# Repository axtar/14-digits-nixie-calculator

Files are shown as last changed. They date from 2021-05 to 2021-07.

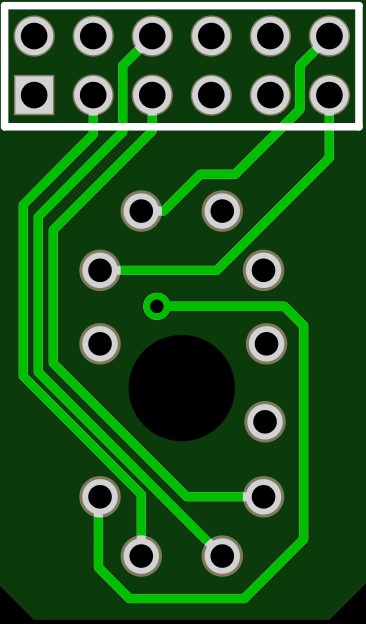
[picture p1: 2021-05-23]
PCB/Pictures/Boards 2D/Nixie Calculator IN-17 Socket Bottom 2D.jpg

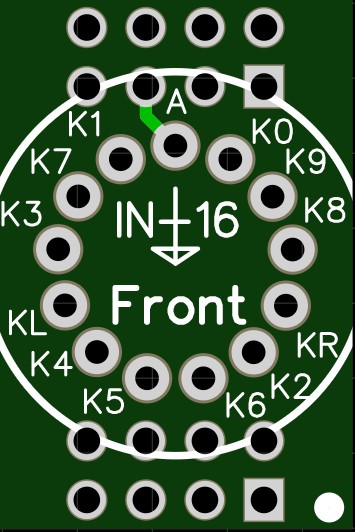
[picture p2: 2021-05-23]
PCB/Pictures/Boards 2D/Nixie Calculator IN-16 Socket Top 2D.jpg

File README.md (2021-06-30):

# 14-digits nixie calculator
## This repository contains some information and ideas for building a nixie calculator.
## WARNING: nixies need high voltage to light up. If you choose to build the calculator, you are doing so at your own risk.
### Hardware status: ready to be reviewed, software status: under construction...
#### Notes:
- I am not affiliated with any of the service providers named in this project.<br>
- **This is not a complete project. Neither the schematic nor the PCB design for the high voltage power supply will be made available.**<br>

readme

**Features:**
-	two versions: IN-16 and IN-17
-	14 digits with decimal points and minus sign
-	socket boards for easy tube replacement
-	mechanical keyboard with 35 switches
-	custom keycap legends and colors
-	15 math operations - the functionality can be extended by adding a second level of functions
-	5 memory operations
-	RTC with battery
-	clock mode
-	stopwatch mode 
-	ESP32 based controller board
-	connectors for PIR, GPS and temperature sensor
-	12V DC input voltage
-	open-source firmware
-	all the settings are adjusted using the keyboard, no network connection is needed
-	3D printed case

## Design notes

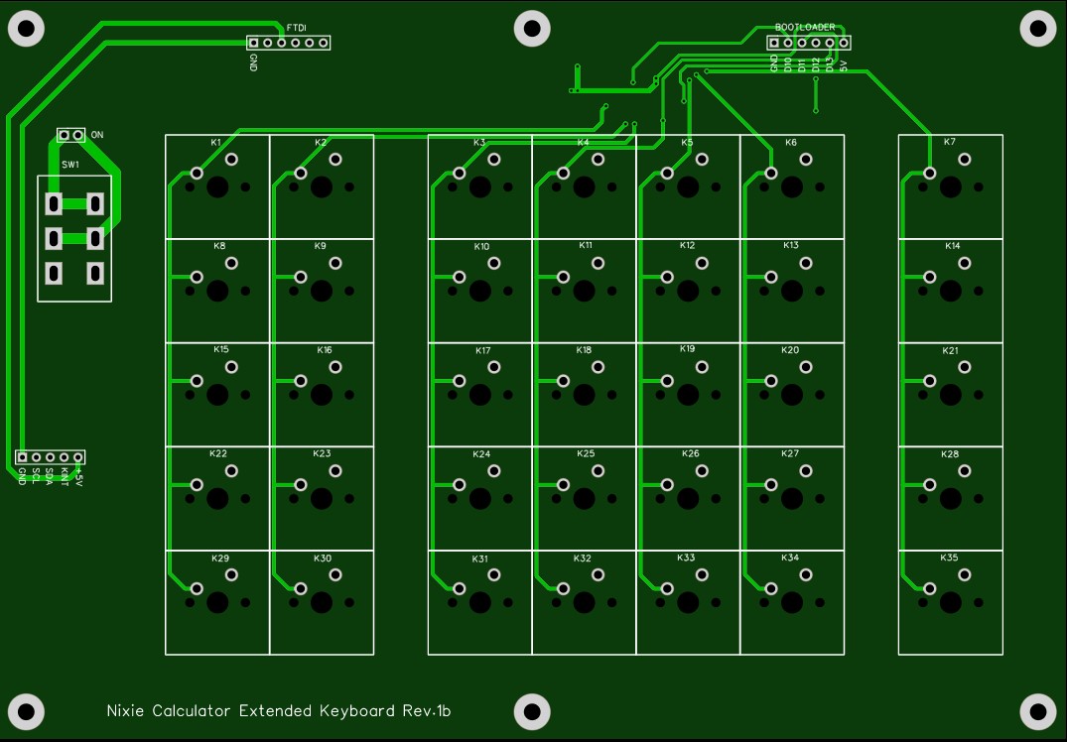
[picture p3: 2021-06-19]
PCB/Pictures/Boards 2D/Nixie Calculator Extended Keyboard Top 2D.jpg

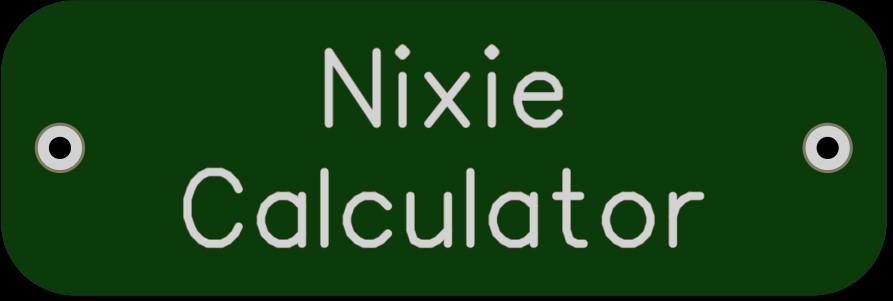
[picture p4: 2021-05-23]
PCB/Pictures/Boards 2D/Nixie Calculator Label Top 2D.jpg

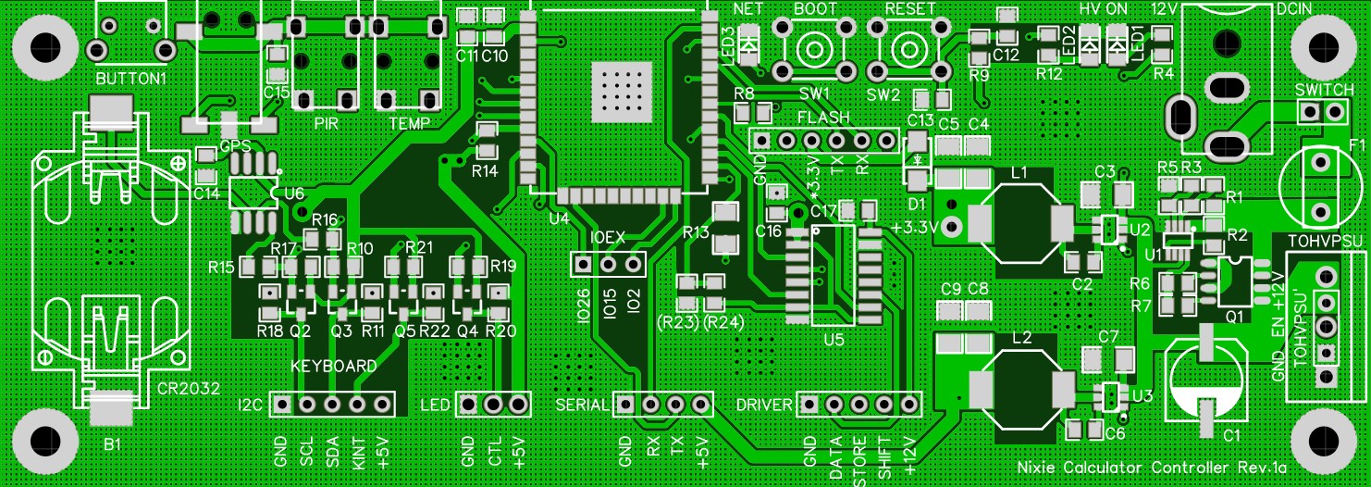
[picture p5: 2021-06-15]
PCB/Pictures/Boards 2D/Nixie Calculator Controller Top 2D.jpg

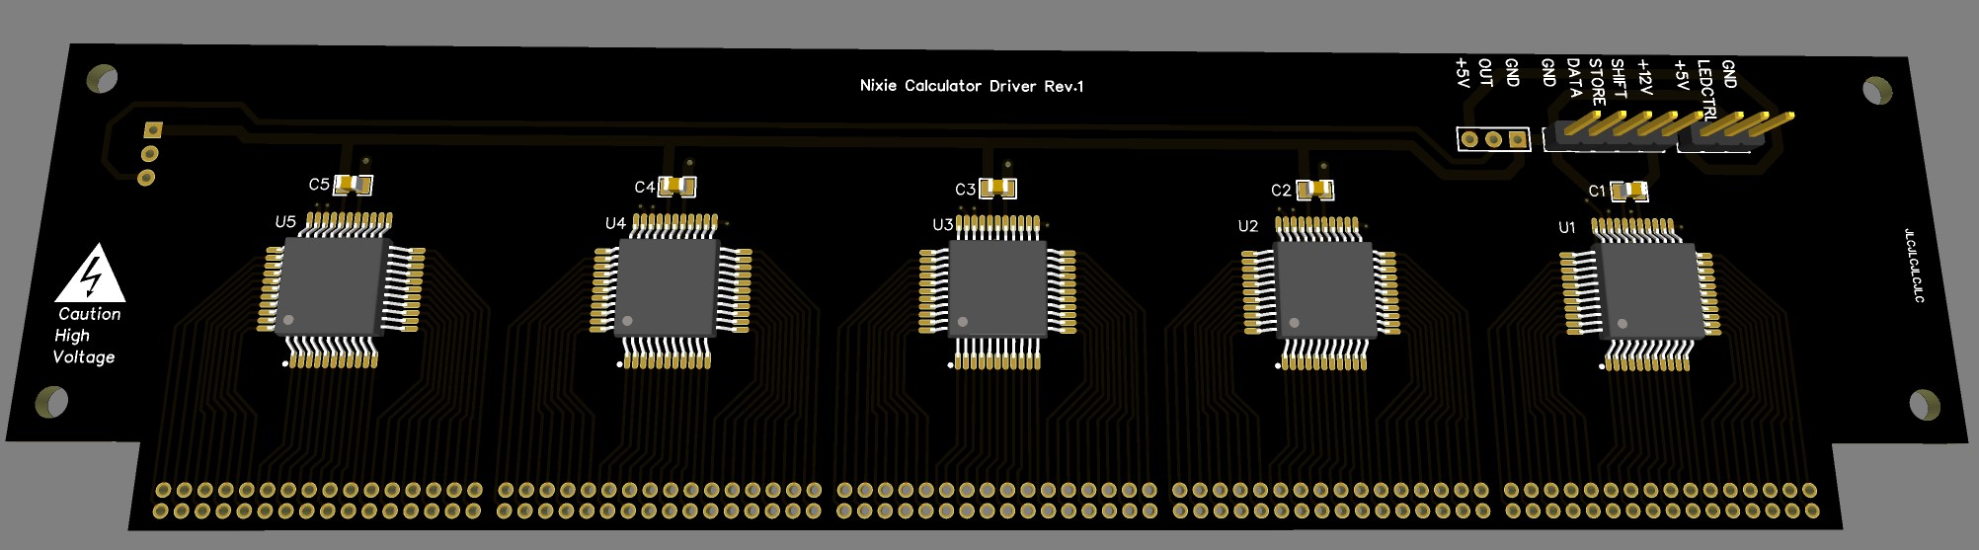
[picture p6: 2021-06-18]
PCB/Pictures/Boards 3D/Nixie Calculator IN-16 Driver Bottom 3D.jpg

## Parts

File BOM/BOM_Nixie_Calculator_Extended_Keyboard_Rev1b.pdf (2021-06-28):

BOM Nixie Calculator Extended Keyboard Rev.1b | 28/06/2021
ID | Quantity | Value | Additional | Designator | Footprint | Type | Manufacturer Part | Manufacturer | Supplier Part | Supplier
1 | 1 | 1M | 1/4W | R1 | 0805 | Resistor | RK73H2ATTD1004F | KOA Speer
2 | 1 | 10k | 1/4W | R2 | 0805 | Resistor | RK73H2ATTD1002F | KOA Speer
3 | 1 | 1k | 1/4W | R3 | 0805 | Resistor | RK73H2ATTD1001F | KOA Speer
4 | 2 | 150 | 1/4W | R4,R5 | 0805 | Resistor | RK73H2ATTD1500F | KOA Speer
5 | 2 | 100n | 50V | C1,C2 | 0805 | Capacitor | C0805C104M5RACTU | KEMET
6 | 2 | 22p | 50V | C3,C4 | 0805 | Capacitor | C0805C220K5HACTU | KEMET
7 | 36 | 1N4148W | | D1-D36 | SOD-123 | Diode | 1N4148W-7-F | Diodes Incorporated
8 | 1 | Crystal 16MHz | | X1 | HC-49/US SMD | Crystal
9 | 1 | ATMEGA328P-AU | | U1 | TQFP-32 | MCU | ATMEGA328P-AU | AVR
10 | 35 | Cherry MX blue | | K1-K35 | | Pushbutton switch | MX1A-E1NW | CHERRY
11 | 1 | Slide switch | | SW1 | | Slide switch | S202031MS02Q | C&K
12 | 1 | 1x2 header/2.54mm | male, right angle | ON | | Header
13 | 1 | 1x5/header/2.54mm | male, right angle | H1 (GND,SCL,SDA,KINT,+5V) | | Header
14 | 2 | 1x6/header/2.54mm | male | FTDI, BOOTLOADER | | Header

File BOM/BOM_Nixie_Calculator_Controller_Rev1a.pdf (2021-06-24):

BOM Nixie Calculator Controller Rev.1a | 24/06/2021
ID | Quantity | Value | Additional | Designator | Footprint | Type | Manufacturer Part | Manufacturer | Supplier Part | Supplier
1 | 1 | 1.2M | 1/4W, 1% | R1 | 0805 | Resistor | RK73H2ATTD1204F | KOA Speer
2 | 1 | 510k | 1/4W | R2 | 0805 | Resistor | RK73H2ATTD5103F | KOA Speer
3 | 1 | 15k | 1/4W, 1% | R3 | 0805 | Resistor | RK73H2ATTD1502F | KOA Speer
4 | 1 | 1k | 1/4W | R4 | 0805 | Resistor | RK73H2ATTDD1001F | KOA Speer
5 | 1 | 47k | 1/4W, 1% | R5 | 0805 | Resistor | RK73H2ATTD4702F | KOA Speer
6 | 2 | 10 | 1/4W | R6,R7 | 0805 | Resistor | RK73H2ATTD10R0F | KOA Speer
7 | 2 | 330 | 1/4W | R8,R12 | 0805 | Resistor | RK73H2ATTD3300F | KOA Speer
8 | 2 | 3.9k | 1/4W | R10,17 | 0805 | Resistor | RK73H2ATTD3901F | KOA Speer
9 | 3 | 4.7k | 1/4W | R11,R14,R18 | 0805 | Resistor | RK73H2ATTD4701F | KOA Speer
10 | 5 | 10k | 1/4W | R9,R19-R22 | 0805 | Resistor | RK73H2ATTD1002F | KOA Speer
11 | 3 | 150 | 1/4W | R13,R15,R16 | 0805 | Resistor | RK73H2ATTD1500F | KOA Speer
12 | 1 | see schematic | 1/4W | R23 | 0805 | Resistor
13 | 1 | see schematic | 1/4W | R24 | 0805 | Resistor
14 | 1 | 220u | 25V | C1 | 8mm dia | Capacitor | GYB1E221MCQ1GS | Nichicon
15 | 9 | 100n | 50V | C2,C6,C10,C12-C17 | 0805 | Capacitor | C0805C104M5RACTU | KEMET
16 | 2 | 10u | 25V | C3,C7 | 1206 | Capacitor | TMK316BJ106MLHT | Taiyo Yuden
17 | 4 | 22u | 25V | C4,C5,C8,C9 | 1206 | Capacitor | TMK316BBJ226ML-T | Taiyo Yuden
18 | 1 | 10u | 16V | C11 | 0805 | Capacitor | GRM21BR61C106KE15K | Murata Electronics
19 | 1 | B340A-13-F | | D1 | SMA | Diode | B340A-13-F | Diodes Incorporated
20 | 1 | LED yellow | | LED1 | 1206 | LED | 599-0240-007F | Dialight
21 | 1 | LED red | | LED2 | 1206 | LED | 599-0210-007F | Dialight
22 | 1 | LED blue | | LED3 | 1206 | LED | 599-0291-007F | Dialight
23 | 1 | 3.9uH inductor | | L1 | 8043 | Inductor | SRU8043-3R9Y | Bourns
24 | 1 | 4.7uH inductor | | L2 | 8043 | Inductor | SRU8043-4R7Y | Bourns
25 | 1 | LTC4365 | | U1 | SOT-8 | IC | LTC4365ITS8-1#TRMPBF | Analog Devices
26 | 1 | AP63203WU-7 | | U2 | TSOT-26-6 | IC | AP63203WU-7 | Diodes Incorporated
27 | 1 | AP63205WU-7 | | U3 | TSOT-26-6 | IC | AP63205WU-7 | Diodes Incorporated
28 | 1 | ESP-WROOM-32E | 16MB | U4 | | MC module | ESP32-WROOM-32E | Espressif Systems
29 | 1 | CD40109B | | U5 | SO-16 | IC | CD40109BNSR | Texas Insruments
30 | 1 | DS3231MZ+ | | U6 | SOIC-8 | IC | DS3231MZ+TRL | Maxim Integrated
31 | 1 | CSD88537ND Dual N | | Q1 | SOIC-8 | Mosfet | CSD88537ND | Texas Insruments
32 | 4 | BSS138 | | Q2,Q3,Q4,Q5 | SOT-23 | Mosfet | BSS138N H6327 | Infineon Technologies
33 | 1 | DC power connector | | DCIN | | DC power connector | PJ-057AH | CUI Devices
34 | 1 | Fuse 1.25A Fast | | F1 | | Fuse | 0034.6015 | Schurter
35 | 1 | Fuse holder | | | | Fuse holder | 0031.7601 | Schurter
36 | 2 | Tactile Switch | | SW1,SW2 | | Switch | TL1105AF160Q | E-Switch
37 | 1 | Tactile Switch | right angle | BUTTON1 | | Switch | TL1105SF160Q | E-Switch
38 | 1 | CR2032 battery holder | | | | Battery holder | SMTU2032-LF | Renata
39 | 1 | CR2032 battery | | B1 | | Battery
40 | 1 | 1x2 header/2.54mm | male | SWITCH | | Header
41 | 2 | 1x3 header/2.54mm | male | LED,IOEX | | Header
42 | *1 | 1x4 header/2.54mm | male | SERIAL | | Header
43 | 2 | 1x5 header/2.54mm | male | DRIVER,I2C | | Header
44 | 1 | 1x6 header/2.54mm | male | FLASH | | Header
45 | 1 | 3 poles terminal block | | TOHVPSU | | Fixed Terminal Block | TB006-508-03BE | CUI Devices
46 | 2 | 3.5mm connector | | TEMP,PIR | see datasheet | 3.5mm connector, 3 pin | 1503 07 | Lumberg
47 | 1 | 3.5mm connector | | GPS | see datasheet | 3.5mm connector, 4 pin | 1503 13 VP3 | Lumberg
* do not populate

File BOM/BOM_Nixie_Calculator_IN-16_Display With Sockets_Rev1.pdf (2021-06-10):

BOM Nixie Calculator IN-16 Display With Sockets Rev.1 | 09/06/2021
ID | Quantity | Value | Additional | Designator | Footprint | Type | Manufacturer Part | Manufacturer | Supplier Part | Supplier
1 | 14 | 15k | 1/4W | R1,R3,R5,R7,R9,R11,R13,R15;R17,R19,R21,R23,R 25,R27 | 0805 | Resistor | RK73H2ATTD1502F | KOA Speer
2 | 14 | 100k | 1/4W | R2,R4,R6,R8,R10,R12,R14,R16,R18,R20,R22,R24, R26,R28 | 0805 | Resistor | RK73H2ATTDD1003F | KOA Speer
3 | 1 | 270k | 1/4W | R29 | 0805 | Resistor | RK73H2ATTD2703F | KOA Speer
4 | 28 | 2x4 header socket 2.00mm | female, 250V | H1_X-H14_X | | Header | A2005HWV-2x4P | CJT
5 | 14 | IN-16 socket board | | | | Board
6 | 14 | IN-16 Nixie | | | | Nixie tube
7 | 28 | 2x4 header 2.00mm | male, 250V | | | Header | A2005WV-2x4P | CJT
8 | 1 | Neon 4mm | | E1 | | Neon lamp
9 | *10 | 2x8 header 2.00mm | male, right angle, 250V | H1-H5 x 2 | | Header | A2005WR-2x8P | CJT
* | 2x16 difficult to find

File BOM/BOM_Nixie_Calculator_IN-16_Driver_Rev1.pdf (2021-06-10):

BOM Nixie Calculator Driver Rev.1 | 09/06/2021
ID | Quantity | Value | Additional | Designator | Footprint | Type | Manufacturer Part | Manufacturer | Supplier Part | Supplier
1 | 6 | 100n | 50V | C1-C6 | 0805 | Capacitor | C0805C104M5RACTU | KEMET
2 | 5 | HV5622 | | U1-U5 | PQFP-44 | IC | HV5622PG-G | Microchip Technology
3 | 6 | Neopixel RGB SK6812 | | D1-D6 | 5050 | RGB LED | SK6812
4 | 1 | 1x3 header, 2.54mm | male | H7 (LED) | | Header
5 | 1 | 1x5 header, 2.54mm | male | H6 (DRIVER) | | Header
H8,H9 (MOTION DETECTOR): do not populate

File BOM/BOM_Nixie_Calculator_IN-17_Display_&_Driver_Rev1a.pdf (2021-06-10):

BOM Nixie Calculator IN-17 Display & Driver With Sockets Rev.1a | 09/06/2021
ID | Quantity | Value | Additional | Designator | Footprint | Type | Manufacturer Part | Manufacturer | Supplier Part | Supplier
1 | 15 | 270k | 1/4W | R2,R4,R6,R8,R10,R12,R14,R16,R 18,R20,R22,R24,R26,R28.R29 | 0805 | Resistor | RK73H2ATTD2703F | KOA Speer
2 | 14 | 22k | 1/4W | R1,R3,R5,R7;R9,R11,R13,R15,R1 7,R19,R21,R23,R25,R27 | 0805 | Resistor | RK73H2ATTD2202F | KOA Speer
3 | 6 | 100n | 50V | C1-C6 | 0805 | Capacitor | C0805C104M5RACTU | KEMET
4 | 5 | HV5622 | | U1-U5 | PQFP-44 | IC | HV5622PG-G | Microchip Technology
| 6 | Neopixel RGB SK6812 | | D1-D6 | 5050 | RGB LED | SK6812
6 | 14 | IN-17 socket board | | | | Board
7 | 14 | IN-17 Nixie | | | | Nixie tube
8 | 14 | 2x6 header 2.00mm | male, 250V | | | Header | A2005WV-2x6P | CJT
9 | 14 | Neon 3mm | | E1-E14
10 | 1 | Neon 4mm | | E15
11 | 14 | 2x6 header 2.00mm | female, 250V | | | | A2005HWV-2x6P | CJT
12 | 1 | 1x5 header 2.54mm | male, right angle | H0 (DRIVER) | | Header
13 | 1 | 1x3 header 2.54mm | male, right angle | H15 (LED) | | Header
14 | 1 | 2 poles terminal block | | HVPSU | | Fixed terminal block | TB006-508-02BE | CUI Devices

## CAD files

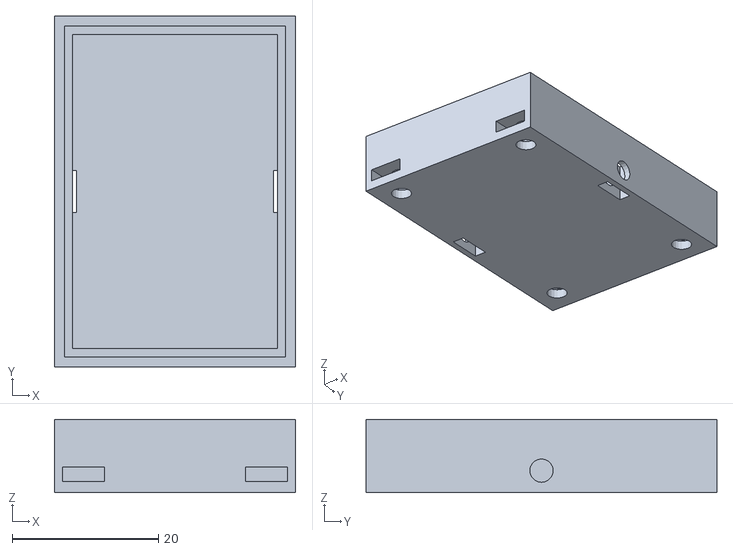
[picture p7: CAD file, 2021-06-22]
Case/STL/HVFIX Part 1.stl
33.0 x 48.0 x 10.0

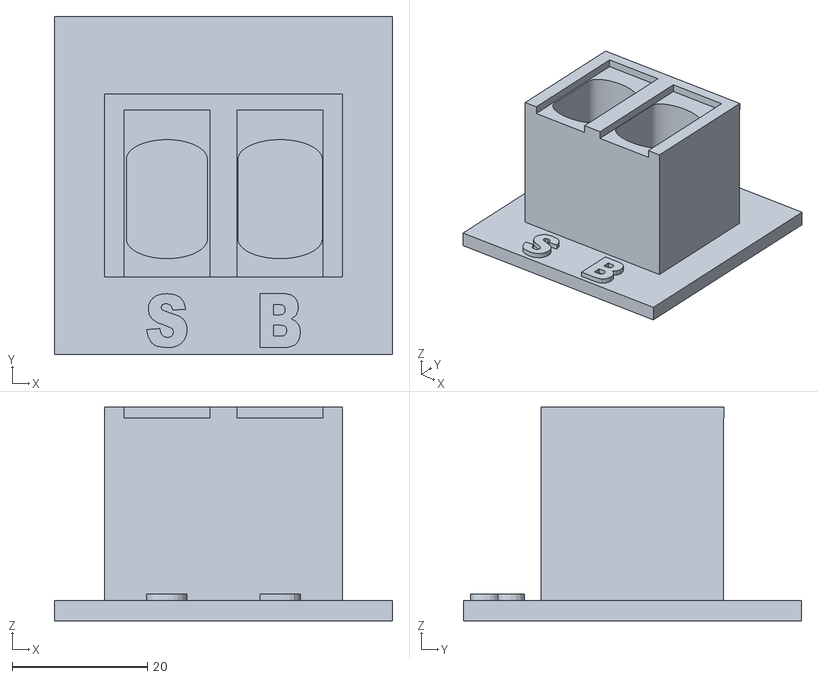
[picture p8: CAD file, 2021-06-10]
Tools/STL/IN-17 Tool.stl
50.0 x 50.0 x 31.6

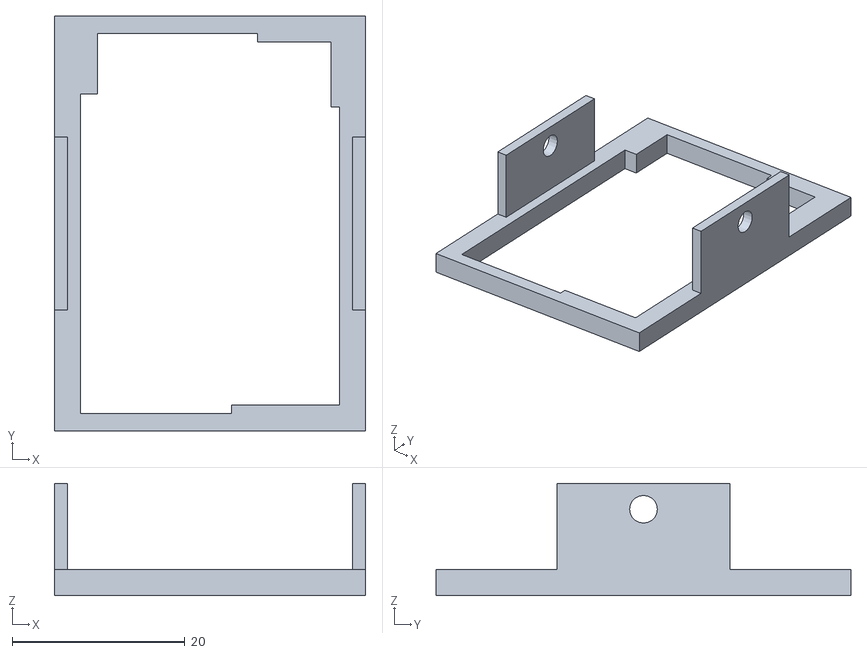
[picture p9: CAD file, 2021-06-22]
Case/STL/HVFIX Part 2.stl
36.0 x 48.0 x 13.0

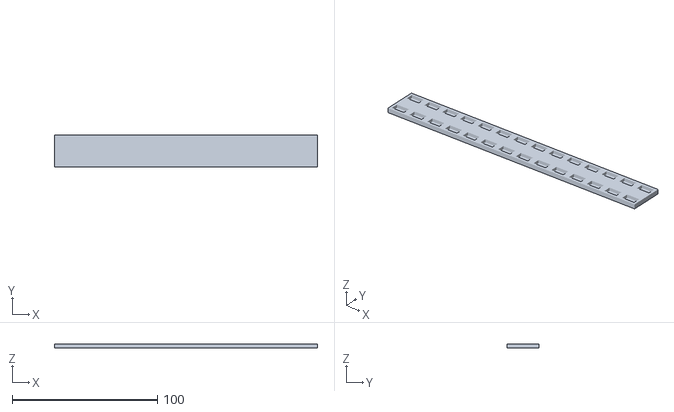
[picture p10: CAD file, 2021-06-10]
Tools/STL/IN-16 Display Tool.stl
181.0 x 22.0 x 3.00

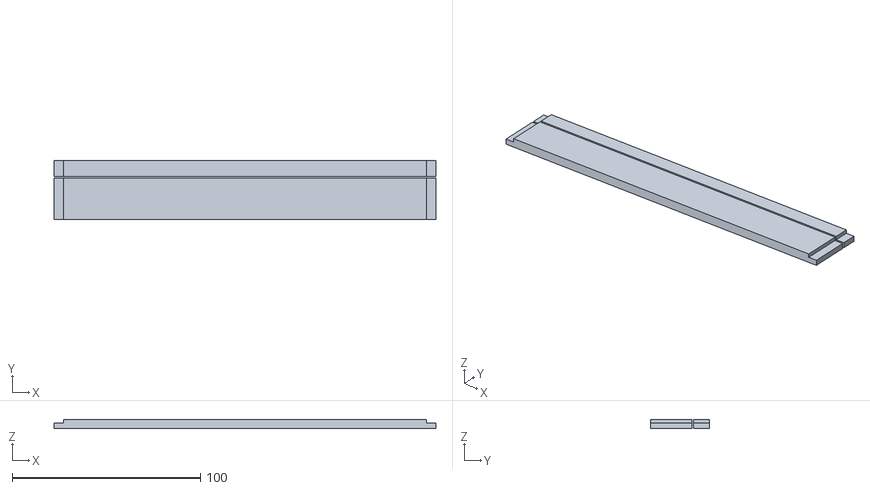
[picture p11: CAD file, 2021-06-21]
Case/STL/Nixie Calculator Optional Front Panels IN-17.stl
203.0 x 31.5 x 5.00

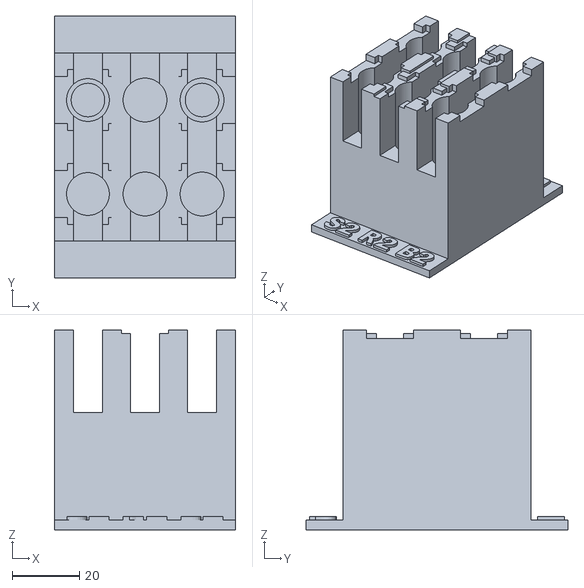
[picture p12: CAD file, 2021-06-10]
Tools/STL/IN-16 Tool.stl
54.0 x 78.0 x 59.6

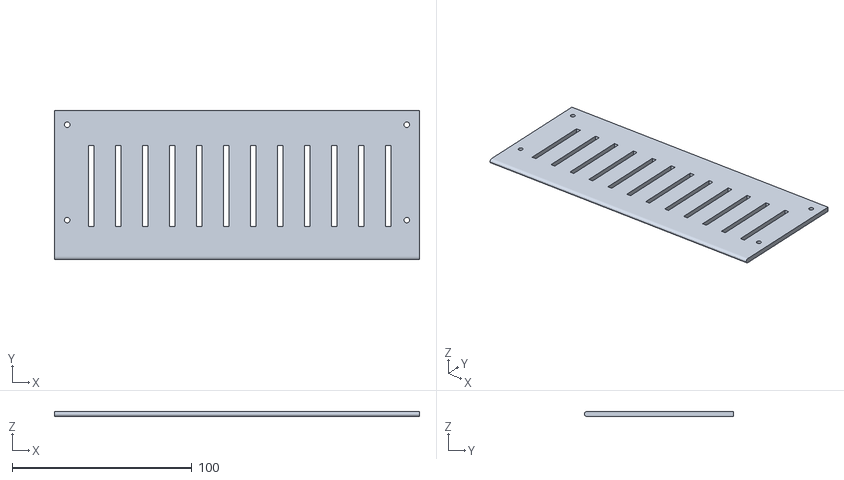
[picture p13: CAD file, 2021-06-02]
Case/STL/Nixie Calculator Case Top.stl
202.8 x 83.0 x 3.00

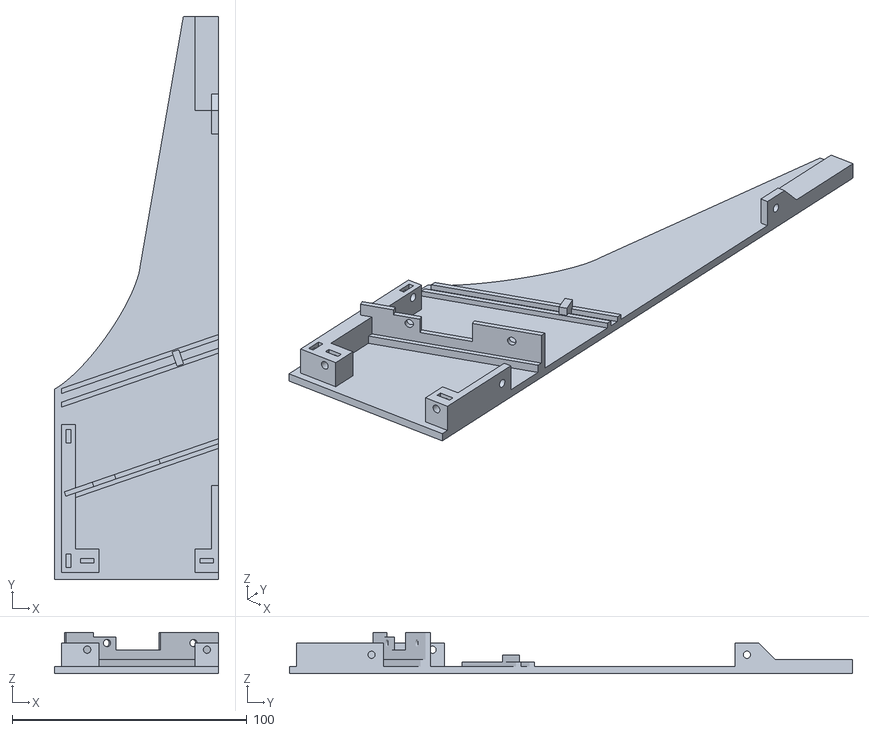
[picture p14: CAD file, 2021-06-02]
Case/STL/Nixie Calculator Case Right IN-17.stl
70.0 x 240.0 x 17.5

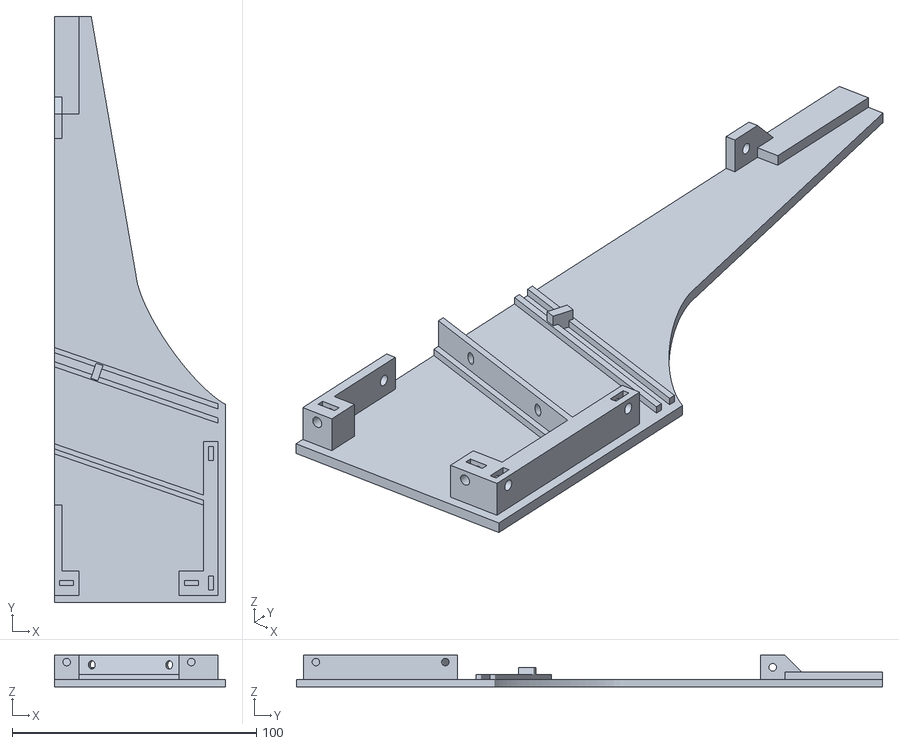
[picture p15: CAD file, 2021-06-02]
Case/STL/Nixie Calculator Case Left IN-16.stl
70.0 x 240.0 x 13.0

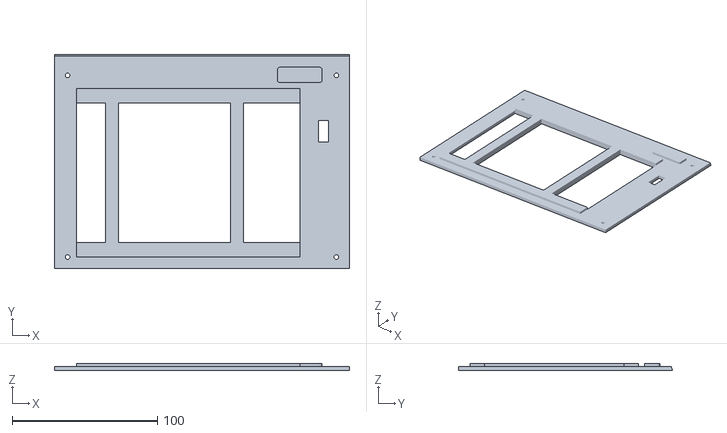
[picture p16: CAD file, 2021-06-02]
Case/STL/Nixie Calculator Case Extended Keyboard Cover.stl
203.0 x 147.5 x 5.00

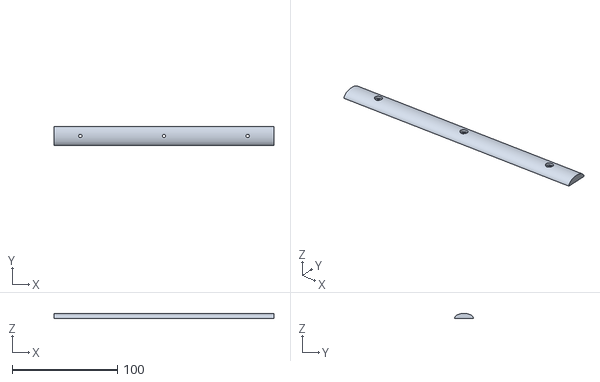
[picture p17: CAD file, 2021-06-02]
Case/STL/Nixie Calculator Case Front.stl
209.0 x 18.0 x 5.00

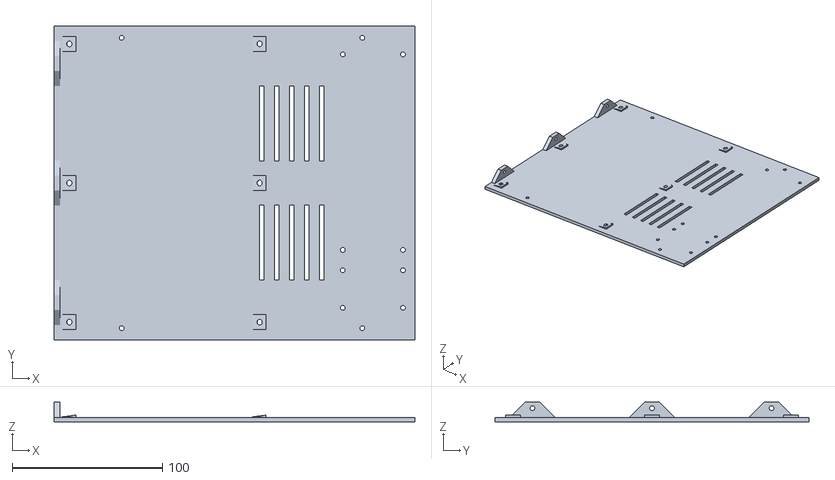
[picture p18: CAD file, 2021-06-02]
Case/STL/Nixie Calculator Case Bottom.stl
240.0 x 209.0 x 13.0

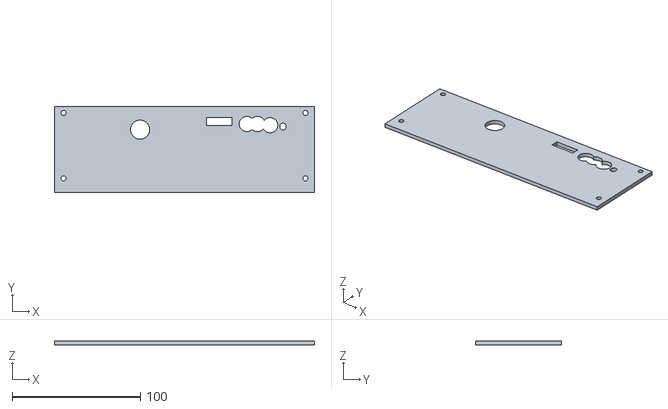
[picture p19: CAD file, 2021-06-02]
Case/STL/Nixie Calculator Case Back Shield.stl
202.8 x 67.0 x 3.00

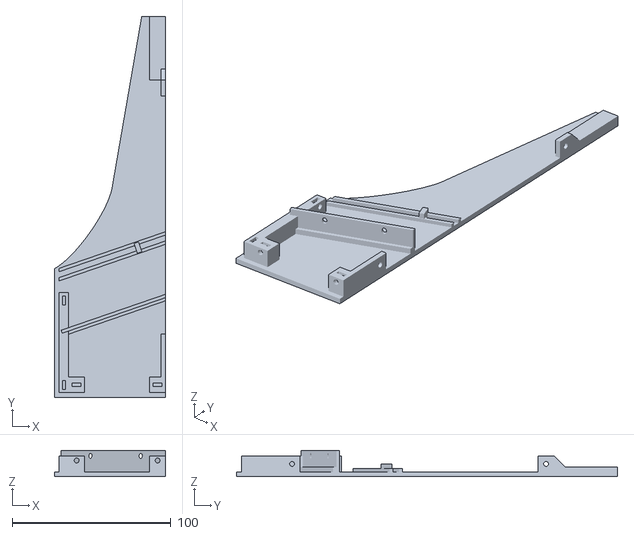
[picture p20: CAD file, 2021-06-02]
Case/STL/Nixie Calculator Case Right IN-16.stl
70.0 x 240.0 x 16.5

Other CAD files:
Case/STL/Nixie Calculator Case Left IN-17.stl

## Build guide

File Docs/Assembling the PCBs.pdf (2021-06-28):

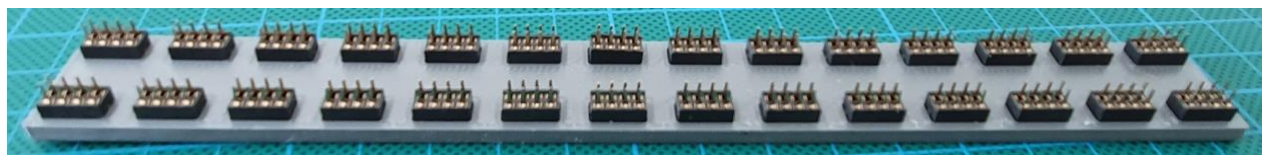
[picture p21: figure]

June 28, 2021 | Draft – Version 0.2 | Page 1 of 3

## Assembling the PCBs

### General information

Since I cannot recommend this project for beginners anyway (high voltage, surface mount, lots of solder joints, etc.), I will skip all the basic stuff and explain just a few things that might be of interest.

### Controller

Start assembling the input protection section including the LED and fuse. Install a jumper on the SWITCH header. According to the datasheet the circuit should protect against overvoltage up to 60V and against reverse voltage down to -40V.

Connect the board to a variable power supply. Start with 12V, the LED should turn on. If you increase the voltage, the LED should turn off around 13.5V. If you decrease the voltage, the LED should turn off around 10V. These are only approximate values.

Then assemble the +3.3V and the +5V supplies and check that all voltages are correct.

Don’t populate the SERIAL header.

### Keyboard

- Solder everything except D1-D35, K1-K35, SW1, H1 and ON
- Flash the bootloader (see Docs/Flashing the bootloader and the firmware.pdf)
- Flash the firmware
- Solder the remaining components

### Display and driver boards

IN-16 Version
The IN-16 display tool can be used to keep things aligned, assuming you use header sockets with similar dimensions. Don’t use too much solder when soldering the socket headers or solder may flow into the sockets.

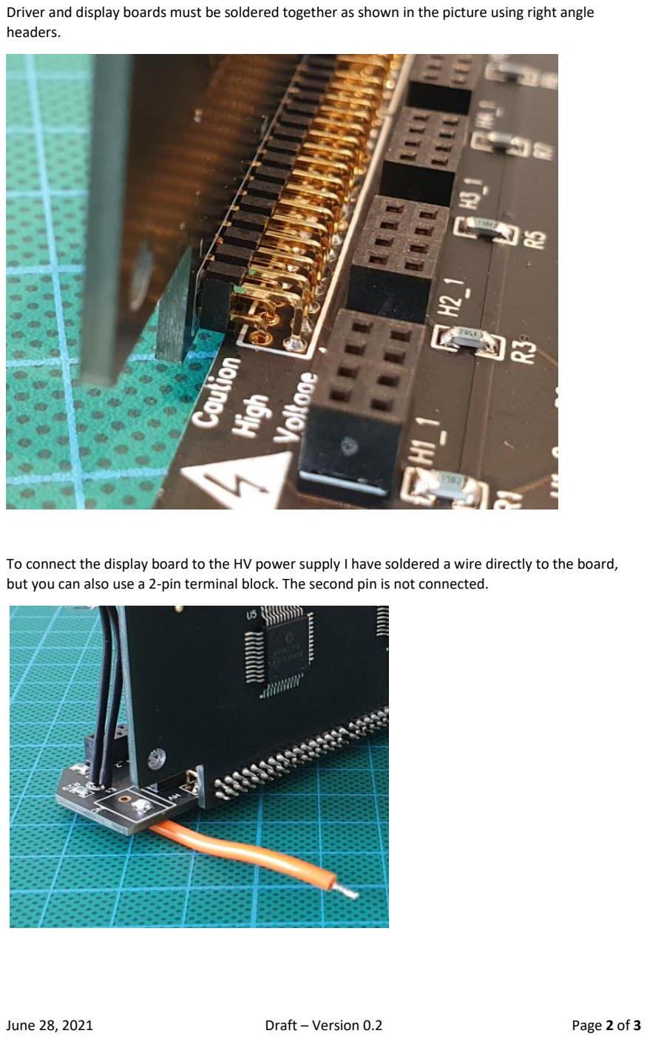
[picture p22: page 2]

Driver and display boards must be soldered together as shown in the picture using right angle headers.

To connect the display board to the HV power supply I have soldered a wire directly to the board, but you can also use a 2-pin terminal block. The second pin is not connected.

Use heat shrink tube (black recommended) for the neon (minus sign). I had to extend the wires a little bit to get the correct height.

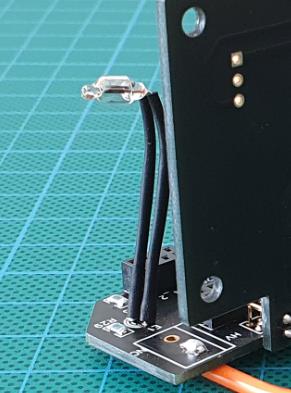
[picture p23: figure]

Don’t populate the H8 and H9 (MOTION DETECTOR) header on the driver board.

IN-17 Version
Use heat shrink tube (black recommended) for all the neons.

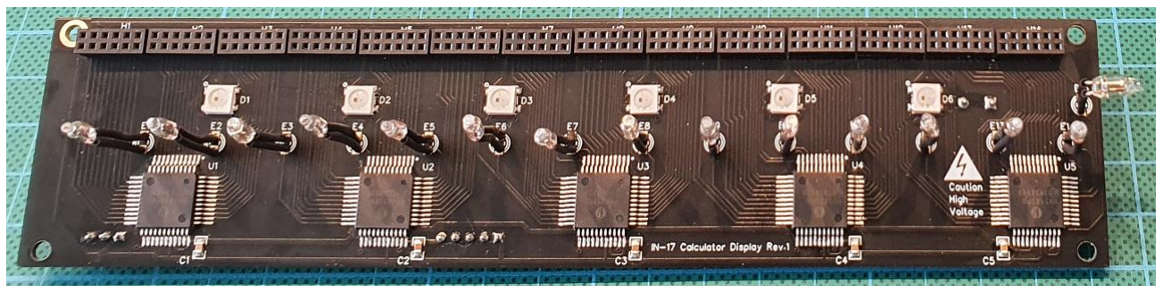
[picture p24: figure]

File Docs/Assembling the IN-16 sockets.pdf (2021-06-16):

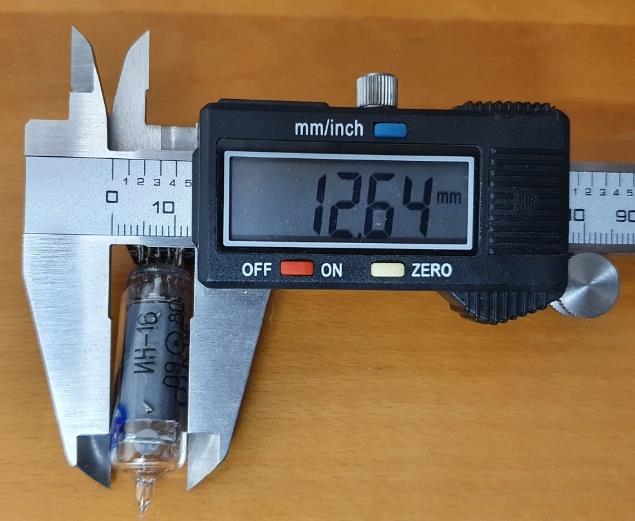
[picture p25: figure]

June 16, 2021 | Draft – Version 0.2 | Page 1 of 9

## Assembling the IN-16 sockets

I don't want to give advice to anyone about soldering nixie tubes, in this document I just show how it works for me.

Nixies are expensive these days and are the most valuable parts of this project, so avoiding mistakes is important.

WARNING: The dimensions of tubes of the same type can vary considerably. Don’t use nixies wider than 13mm for this project if you cannot compensate the difference with the adjacent tubes! Also check, that the exhaust tips are not too long to fit in the case.

I didn’t have any problems with any of my (non-matched) tubes.

It is not that easy to align 14 tubes, so I ended up with a rather "complicated" method with a 3D printed auxiliary tool. Of course, if you prefer, you can do it by eye.

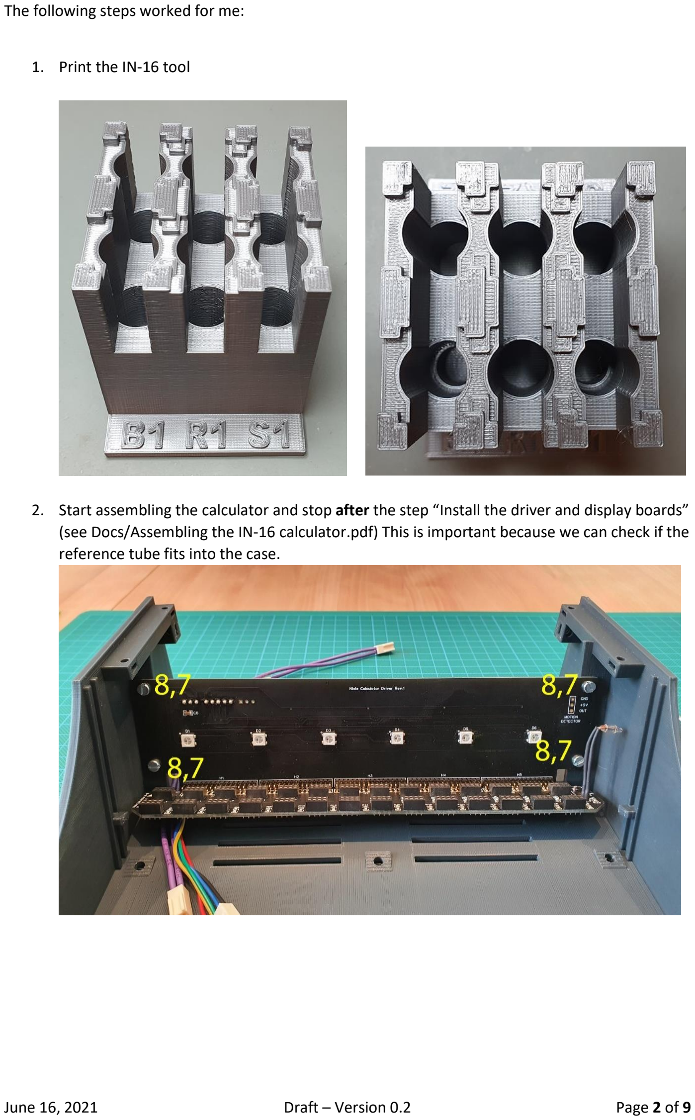
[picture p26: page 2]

The following steps worked for me:

1. Print the IN-16 tool
2. Start assembling the calculator and stop after the step “Install the driver and display boards” (see Docs/Assembling the IN-16 calculator.pdf) This is important because we can check if the reference tube fits into the case.

3. Take a spare IN-16 display board and 2 spare socket headers and solder the header H1_1 and H1_2 to the board. If you want to test the nixies you can also populate R1 and R2.

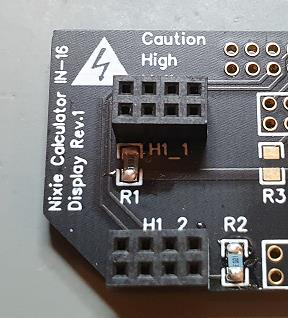
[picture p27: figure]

Now we are ready to build the reference tube socket. Of all the IN-16s that you plan to use for this project, take the one with the longest exhaust tip.

4. Carefully remove the plastic spacer and find the anode lead (double-check with IN-16 datasheet!) Leave the anode lead as it is, take the next (adjacent) lead and cut about 1mm from the free end of the lead. Then take the next lead and cut 2mm, take the next lead and cut 3mm and so on…

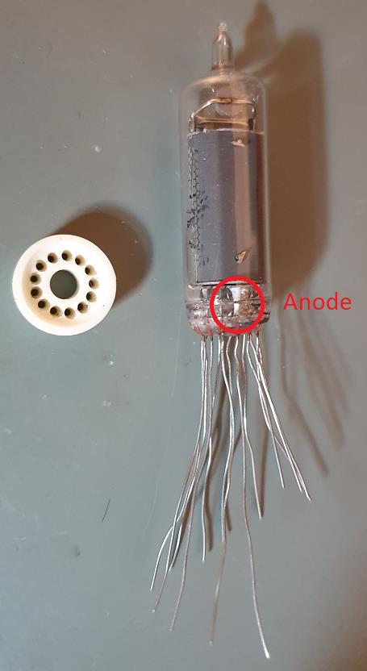
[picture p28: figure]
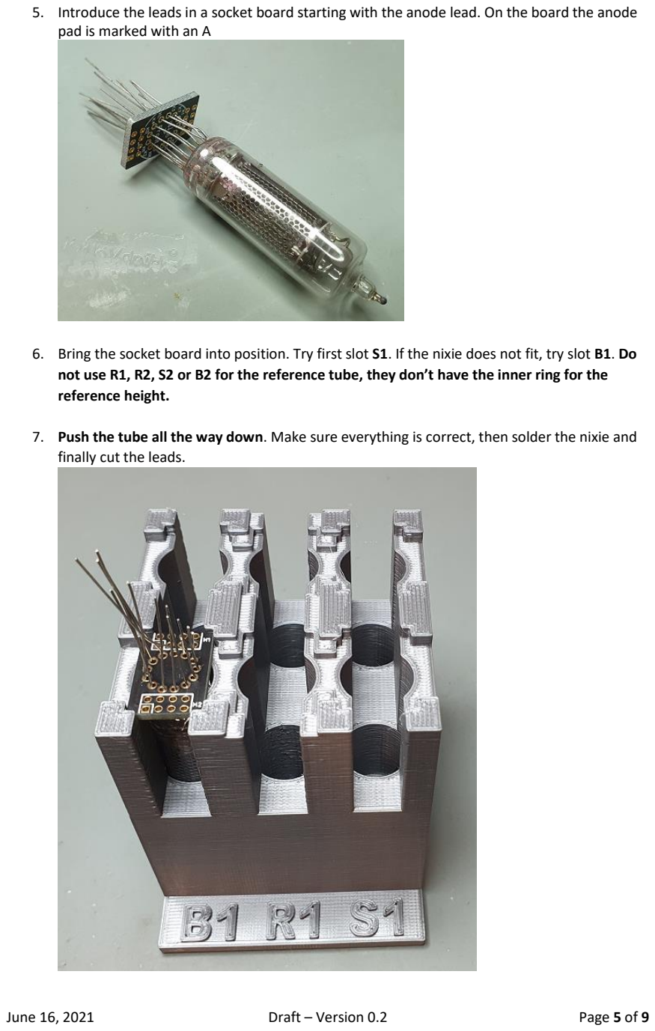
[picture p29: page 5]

5. Introduce the leads in a socket board starting with the anode lead. On the board the anode pad is marked with an A
6. Bring the socket board into position. Try first slot S1. If the nixie does not fit, try slot B1. Do not use R1, R2, S2 or B2 for the reference tube, they don’t have the inner ring for the reference height.
7. Push the tube all the way down. Make sure everything is correct, then solder the nixie and finally cut the leads.

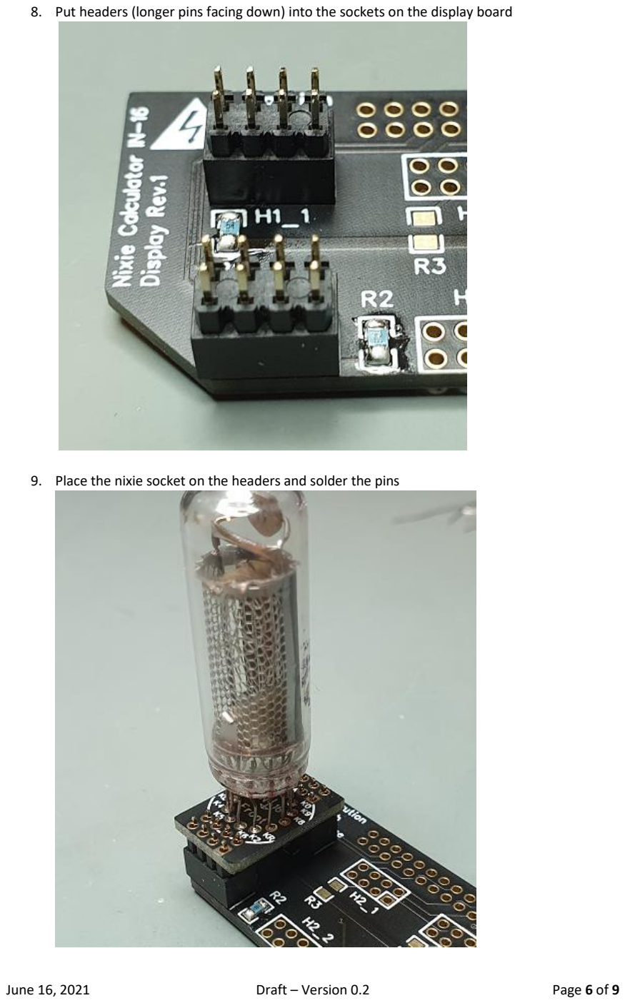
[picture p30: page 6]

8. Put headers (longer pins facing down) into the sockets on the display board
9. Place the nixie socket on the headers and solder the pins

10. You can now test the nixie

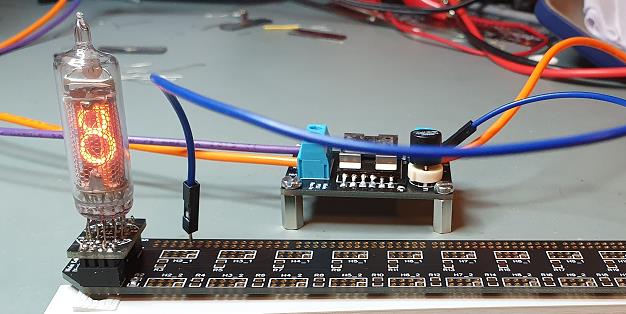
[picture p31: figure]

11. Check if the nixie with the socket fits into the case. If everything is fine, this is now your reference tube.

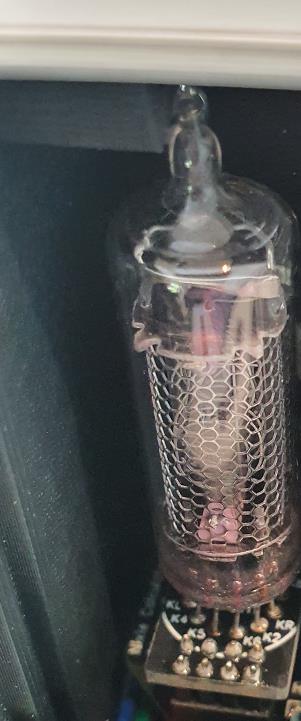
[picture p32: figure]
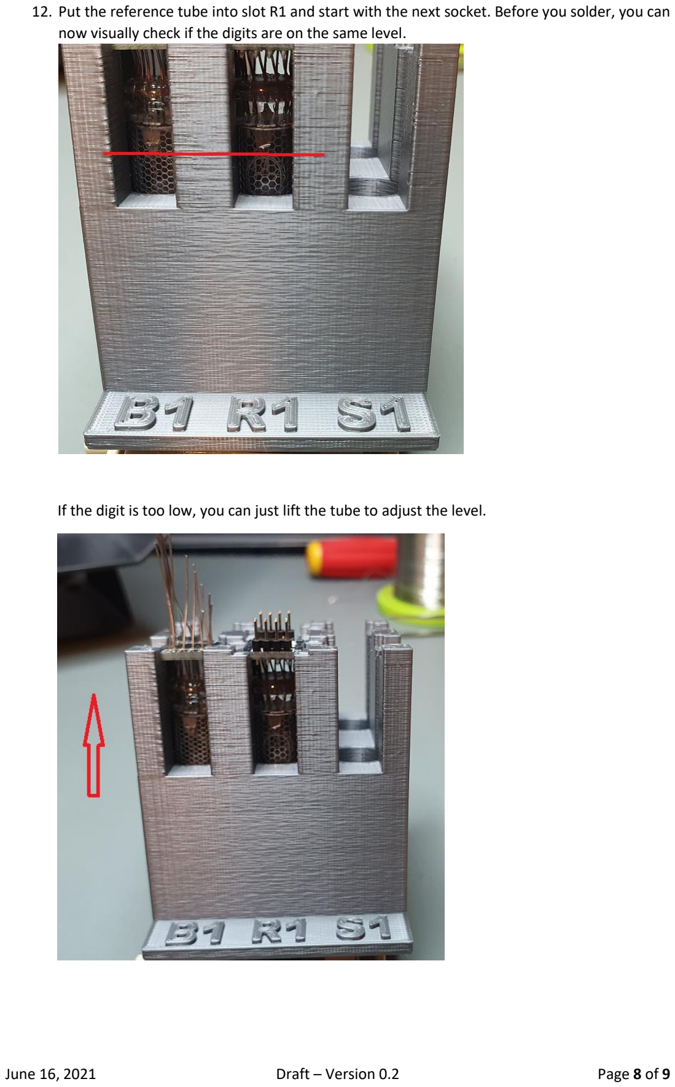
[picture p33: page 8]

12. Put the reference tube into slot R1 and start with the next socket. Before you solder, you can now visually check if the digits are on the same level.

If the digit is too low, you can just lift the tube to adjust the level.

If the digit is too high, you have to switch to the “2” slots and push the tube down to adjust the level.

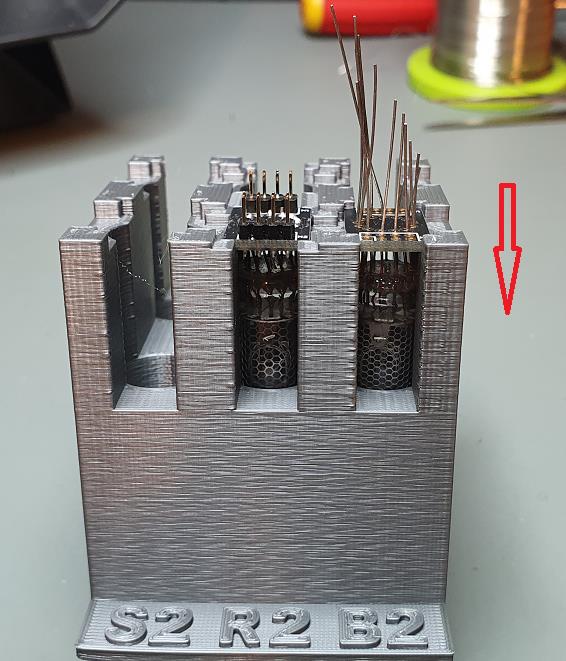
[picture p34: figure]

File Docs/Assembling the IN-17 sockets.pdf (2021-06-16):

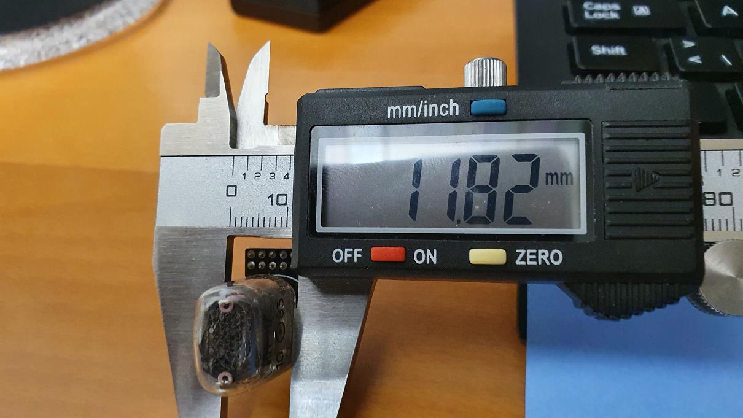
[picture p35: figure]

June 16, 2021 | Draft – Version 0.1 | Page 1 of 6

## Assembling the IN-17 sockets

I don't want to give advice to anyone about soldering nixie tubes, in this document I just show how it works for me.

Nixies are expensive these days and are the most valuable parts of this project, so avoiding mistakes is important.

WARNING: The dimensions of tubes of the same type can vary considerably. Don’t use nixies wider than 13mm for this project if you cannot compensate the difference with the adjacent tubes!

I didn’t have any problems with any of my (non-matched) tubes.

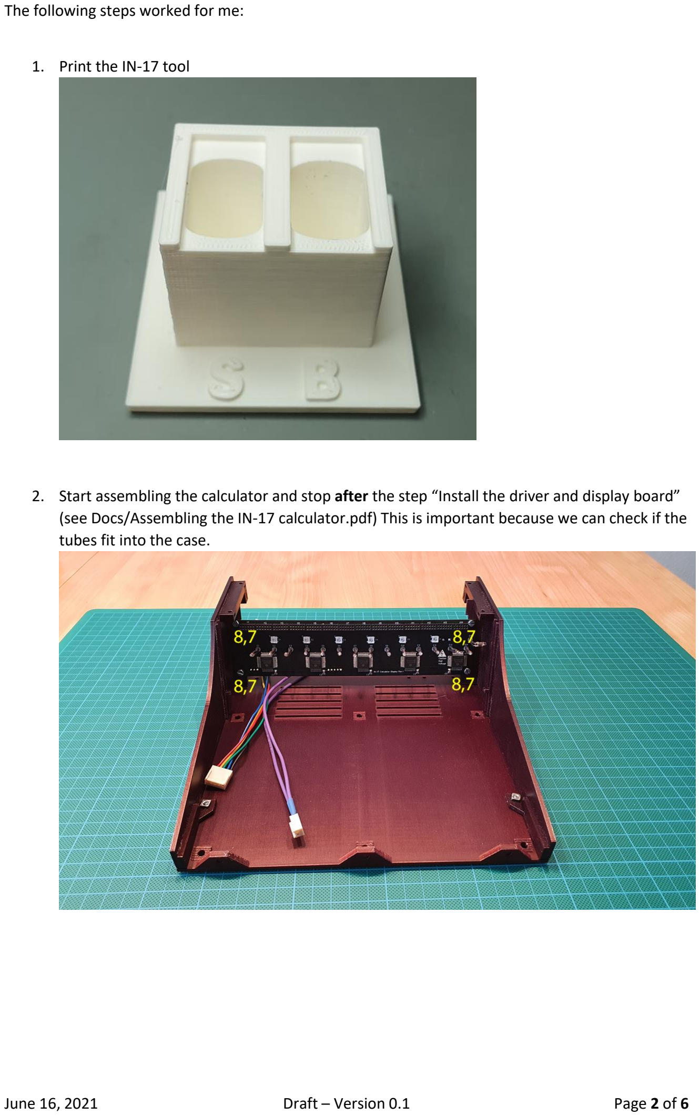
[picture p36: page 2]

The following steps worked for me:

1. Print the IN-17 tool
2. Start assembling the calculator and stop after the step “Install the driver and display board” (see Docs/Assembling the IN-17 calculator.pdf) This is important because we can check if the tubes fit into the case.

3. Carefully remove the plastic spacer and find the anode lead (double-check with IN-17 datasheet!) Leave the anode lead as it is, take the next (adjacent) lead and cut about 1mm from the free end of the lead. Then take the next lead and cut 2mm, take the next lead and cut 3mm and so on…

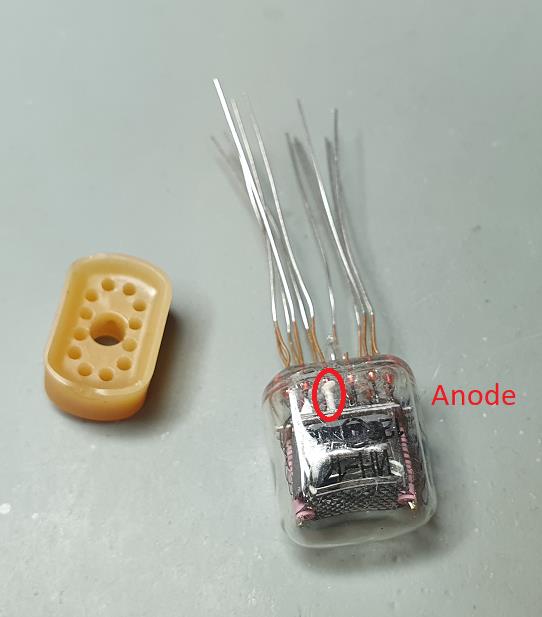
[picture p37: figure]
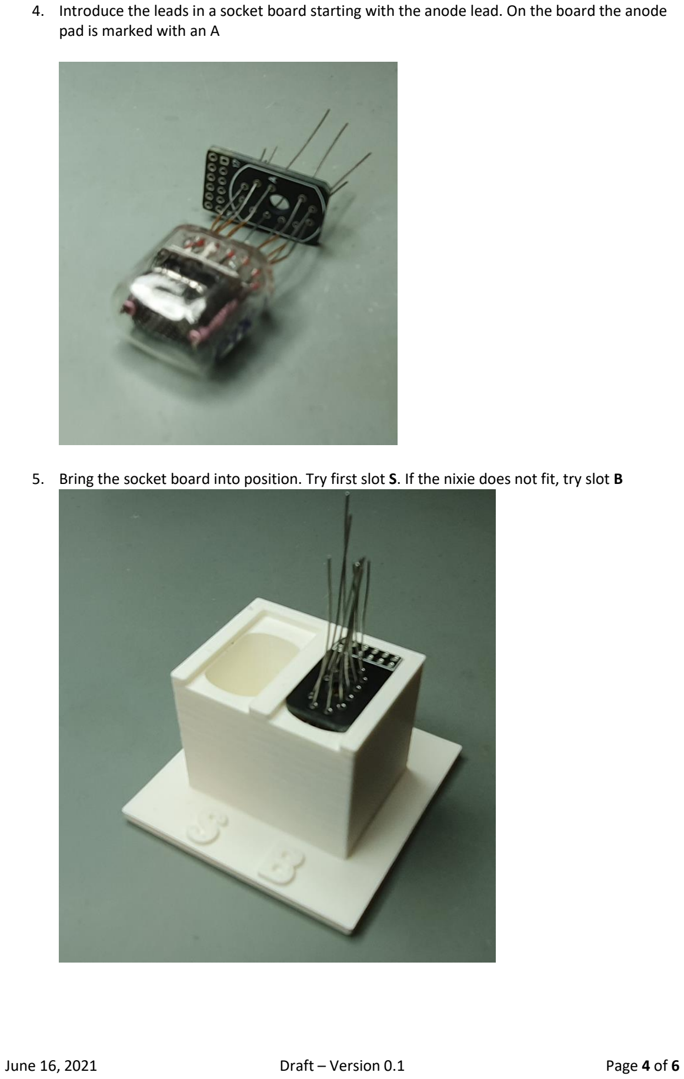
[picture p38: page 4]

4. Introduce the leads in a socket board starting with the anode lead. On the board the anode pad is marked with an A
5. Bring the socket board into position. Try first slot S. If the nixie does not fit, try slot B

6. Push the tube all the way down. Unfortunately, the tool does only help for setting the distance between socket board and tube but not for the alignment. I start soldering only one lead and then I check the alignment. If the alignment is ok, I solder the opposite lead, check again and so on.

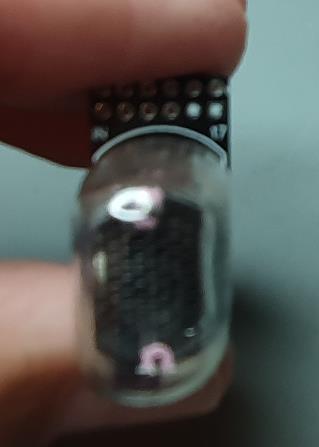
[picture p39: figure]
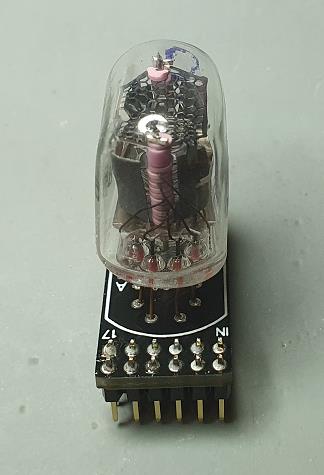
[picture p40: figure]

7. Solder the header

8. Verify that the nixie with the socket fits into the case by installing the nixie and the front panel.

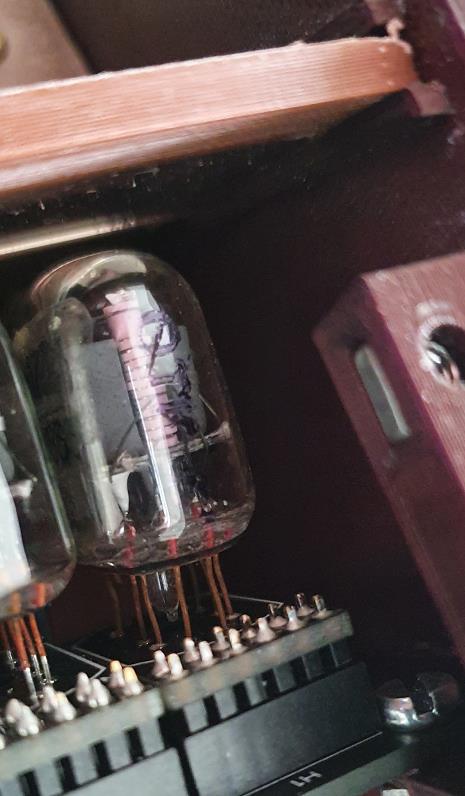
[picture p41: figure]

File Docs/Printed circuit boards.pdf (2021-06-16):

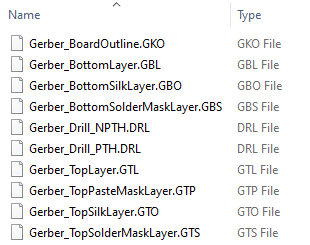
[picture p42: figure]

June 12, 2021 | Draft - Version 0.1 | Page 1 of 1

## Printed circuit boards

You can order your boards directly in EasyEDA or you can generate the gerber files and send them to your favorite manufacturer.

The case has been designed for 1.6mm boards with one exception: the label must be a 1mm board.

For this project I recommend ENIG black for the label board and lead-free (RoHS) black for the other boards. Black boards look better behind the acrylic panel.

We will need a spare IN-16 display board (see Docs/Assembling the IN-16 sockets.pdf)

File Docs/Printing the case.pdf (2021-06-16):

June 16, 2021 | Draft - Version 0.2 | Page 1 of 1

## Printing the case

The required print area is 240mm x 210mm.

There are two versions of the right and left case parts: IN-16 and IN-17.

I print all the parts without support structures, that works for me.

I’m not an expert, but here are some tips on how to get a nicer finish on the parts:

- 0-degree fill angle
- bottom fill patterns
- ironing feature (you may need to modify and turn the parts)
- sandpaper, primer and paint
- PLA wood filament

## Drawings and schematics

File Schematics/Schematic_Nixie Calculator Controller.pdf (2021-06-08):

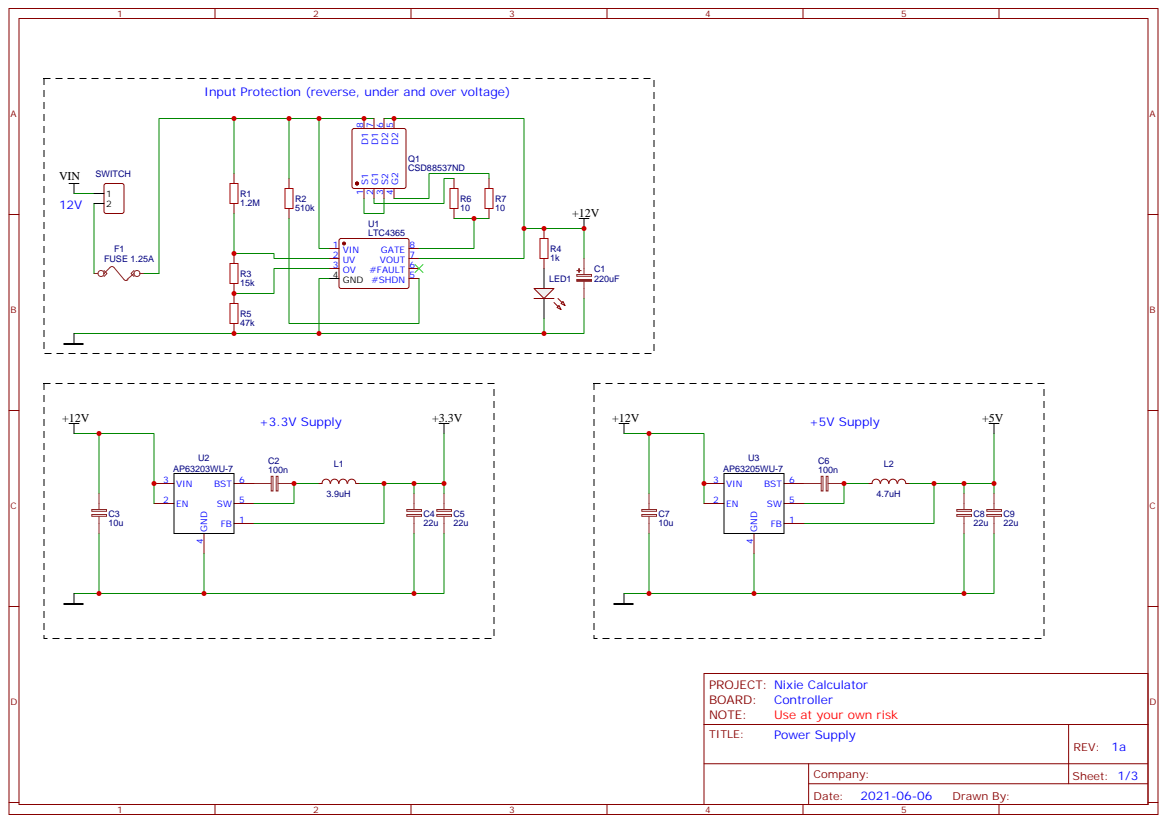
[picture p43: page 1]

Input Protection (reverse, under and over voltage)

IO0 25 IO4 26 IO16 27 IO17 28 IO5 29 IO18 30 IO19 31 NC 32 IO21 33 RXD0 34 TXD0 35 IO22 36 IO23 37 GND 38

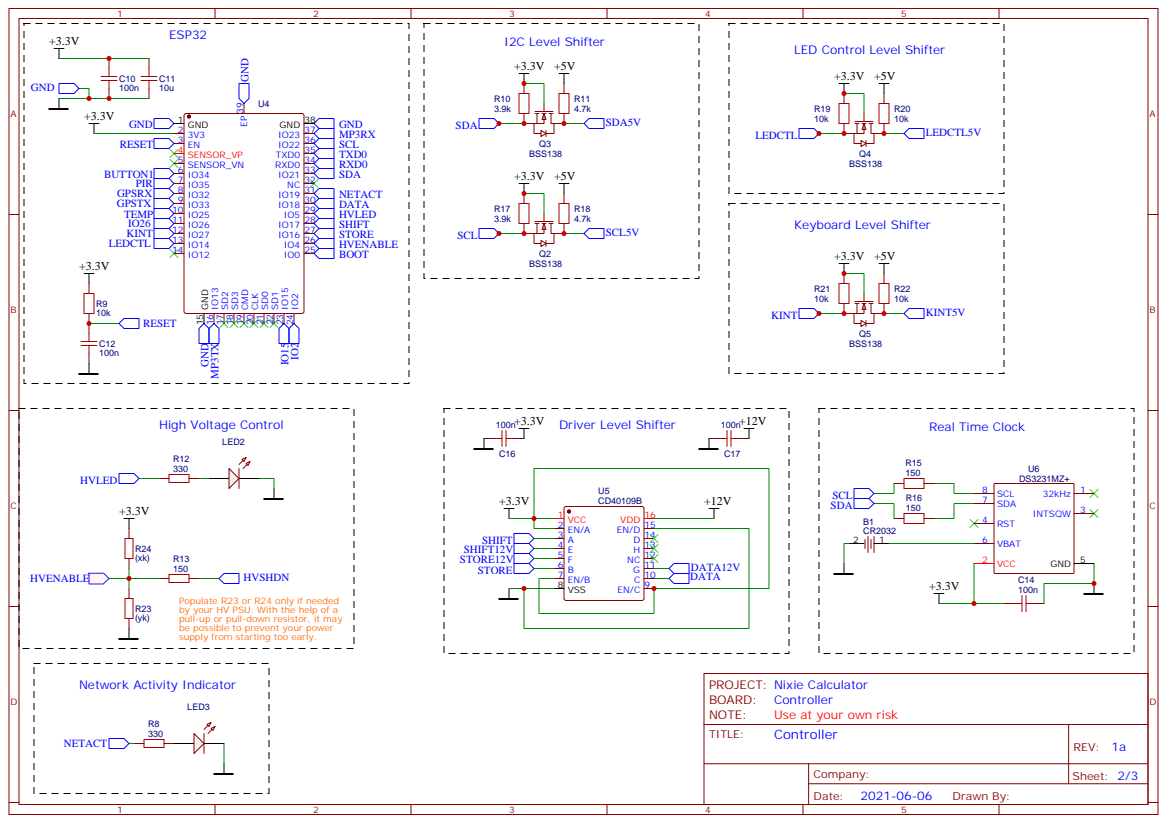
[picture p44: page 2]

LED Control Level Shifter

Populate R23 or R24 only if needed
by your HV PSU. With the help of a
pull-up or pull-down resistor, it may
be possible to prevent your power
supply from starting too early.

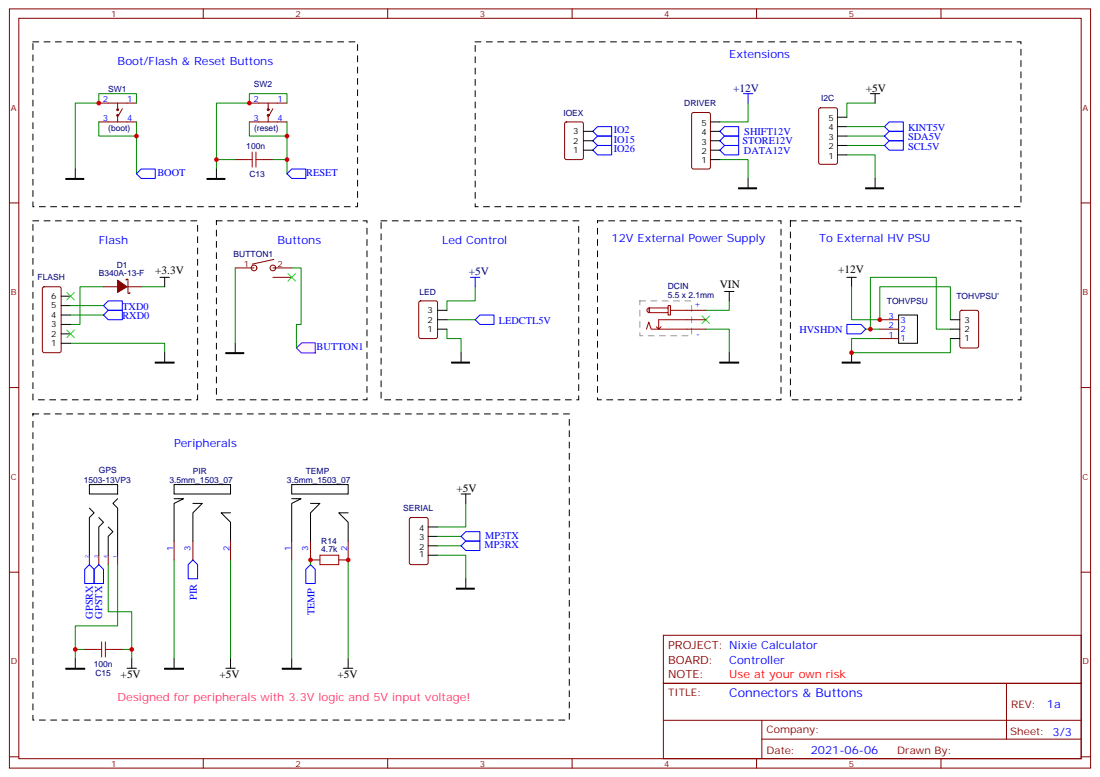
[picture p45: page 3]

Boot/Flash & Reset Buttons

Designed for peripherals with 3.3V logic and 5V input voltage!

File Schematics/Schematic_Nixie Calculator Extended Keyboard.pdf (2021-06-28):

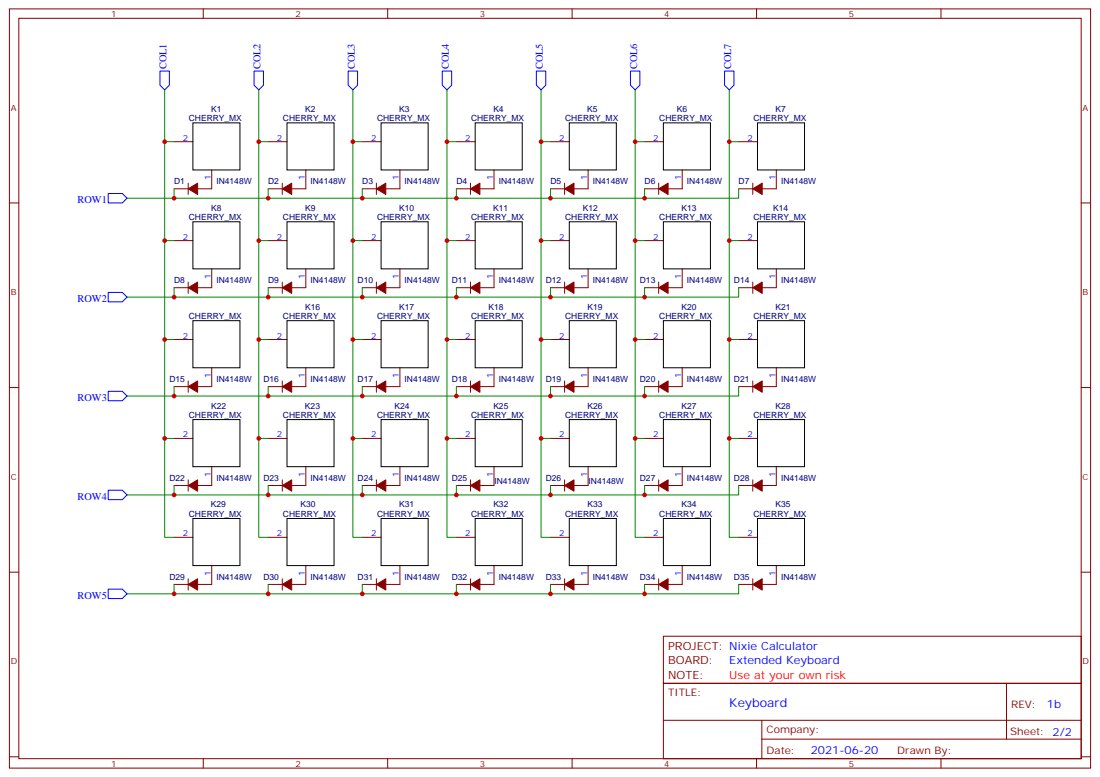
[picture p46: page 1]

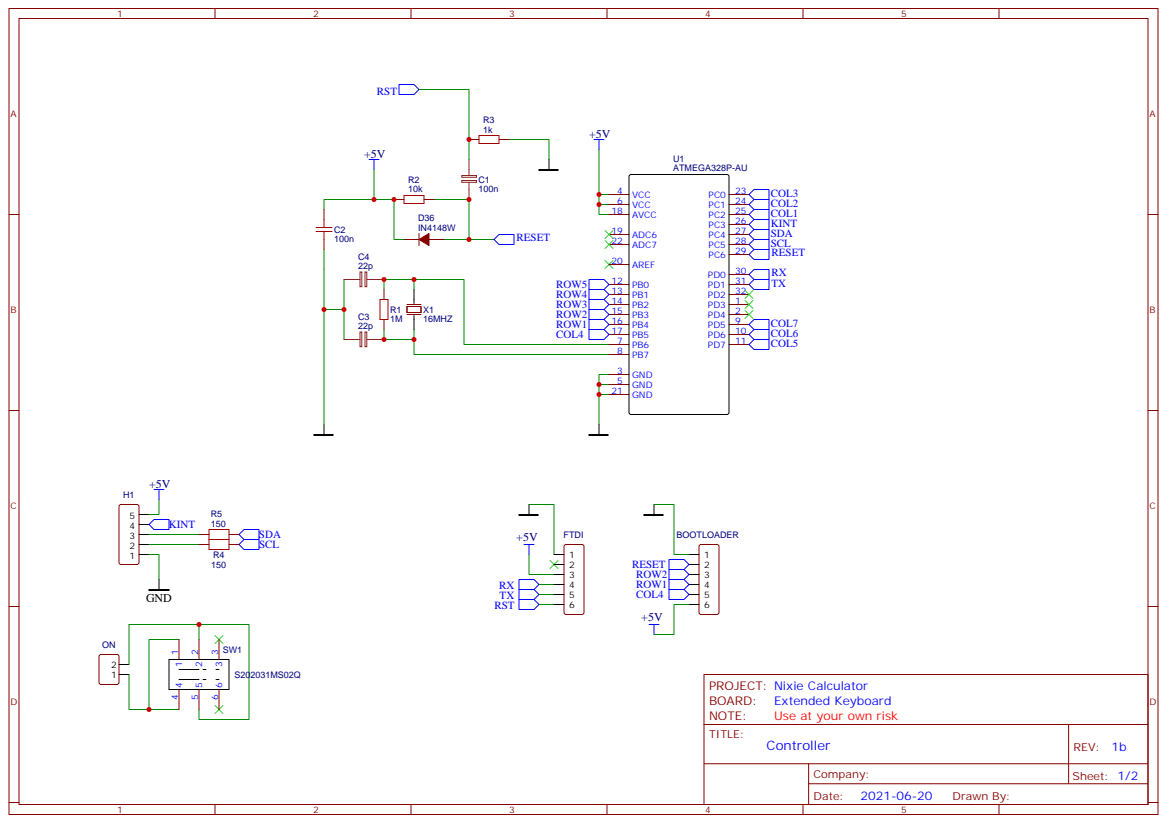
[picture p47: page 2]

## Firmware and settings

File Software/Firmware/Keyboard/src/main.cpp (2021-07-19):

// Nixie Calculator Keyboard Firmware
// Version 0.1.6 (beta) - July 19, 2021

// Copyright (C) 2021 highvoltglow
// Licensed under the MIT License

// the keyboard receives commands from the controller using I2C
// keyboard events are sent to the controller using a serial interface

// commands:
// CMD_RESET                      -> resets the keyboard
// CMD_GETVERSION                 -> prepares for version request
// CMD_SETHOLDTIME                -> sets the time (ms) after a pressed key changes to hold state
// CMD_SETDEBOUNCETIME            -> sets the debounce time (ms), modify only if you get more events as expected
// CMD_SETAUTOREPEATINTERVAL      -> sets the time (ms) between autorepeat events if a key is hold
// CMD_SETFASTAUTOREPEATINTERVAL  -> sets the time (ms) between autorepeat events after the fast autorepeat delay
// CMD_SETFASTAUTOREPEATDELAY     -> sets the number of autorepeat events before changing to the fast autorepeat interval

// default event sequence:
// key pressed  -> "pressed" event
// key released -> "released" event, "idle" event

// event sequence with default values and hold:
// ------------------------------------------------------------------------------------------------
// | holdTime = 1000, autoRepeatInterval = 0, fastAutoRepeatInterval = 0, fastAutoRepeatDelay = 0 |
// ------------------------------------------------------------------------------------------------
// key pressed  -> "pressed" event
// time +1000   -> "hold" event
// ...
// key released -> "released" event, "idle" event

// event sequence example with auto repeat:
// ----------------------------------------------------------------------------------------------------
// | holdTime = 1000, autoRepeatInterval = 500, fastAutoRepeatInterval = 250, fastAutoRepeatDelay = 3 |
// ----------------------------------------------------------------------------------------------------
// key pressed  -> "pressed" event
// time +1000   -> "hold" event, "autorepeat" event
// time +1500   -> "autorepeat" event
// time +2000   -> "autorepeat" event
// time +2250   -> "autorepeat" event (fast)
// time +2500   -> "autorepeat" event (fast)
// ...
// key released -> "released" event, "idle" event

// includes
#include <Arduino.h>
#include <SoftwareSerial.h>
#include <Keypad.h>
#include <Wire.h>

// #define SERIALDEBUG

// version information
#define VERSION_MAJOR 0
#define VERSION_MINOR 1
#define VERSION_REVISION 6

// I2C address
#define I2C_ADDRESS 2

// commands
#define CMDINDENTIFIER '@'
#define CMD_RESET 1
#define CMD_GETVERSION 2
#define CMD_SETHOLDTIME 3
#define CMD_SETDEBOUNCETIME 4
#define CMD_SETAUTOREPEATINTERVAL 5
#define CMD_SETFASTAUTOREPEATINTERVAL 6
#define CMD_SETFASTAUTOREPEATDELAY 7

// keys arranged in 7 x 5 matrix
#define ROWS ((const byte)7)
#define COLS ((const byte)5)

// pins
#define PIN_KINT 17
#define PIN_DUMMY_RX 2

// this is an additional KeyState used
// for generated repeat events
#define KEYSTATE_AUTOREPEAT 4

typedef struct
{
  uint8_t keyCode;
  unsigned long holdTimestamp;
  uint autoRepeatCount;
} HOLD_INFO;

// key values
char keys[ROWS][COLS] = {{1, 2, 3, 4, 5},
                         {6, 7, 8, 9, 10},
                         {11, 12, 13, 14, 15},
                         {16, 17, 18, 19, 20},
                         {21, 22, 23, 24, 25},
                         {26, 27, 28, 29, 30},
                         {31, 32, 33, 34, 35}};

// matrix pins
byte rowPins[ROWS] = {16, 15, 14, 13, 7, 6, 5};
byte colPins[COLS] = {12, 11, 10, 9, 8};

// keypad instance
Keypad keypad = Keypad(makeKeymap(keys), rowPins, colPins, ROWS, COLS);

// serial interface for keyboard events
SoftwareSerial kSerial(PIN_DUMMY_RX, PIN_KINT);

// key hold timestamp array for auto repeat function
HOLD_INFO keyHoldInfo[LIST_MAX];

volatile uint holdTime = 1000;
volatile uint debounceTime = 10;
volatile uint autoRepeatInterval = 0;
volatile uint fastAutoRepeatInterval = 0;
volatile uint fastAutoRepeatDelay = 0;
volatile int pendingRequest;

// forward declarations
void (*reset)(void) = 0;
void receiveEvent(int count);
void requestEvent();
void onReset();
void onGetVersion();
void onSetHoldTime();
void onSetDebounceTime();
void onSetAutoRepeatInterval();
void onSetFastAutoRepeatInterval();
void onSetFastAutoRepeatDelay();

void deleteKeyHoldInfo(uint8_t keyCode);
void setKeyHoldInfo(uint8_t keyCode);
void initKeyHoldInfo();

void setup()
{
#ifdef SERIALDEBUG
  Serial.begin(9600);
#endif

  // init serial connection
  kSerial.begin(9600);

  // init the hold timestamp table
  initKeyHoldInfo();

  // set default values
  keypad.setHoldTime(holdTime);
  keypad.setDebounceTime(debounceTime);
  pendingRequest = -1;

  // init I2C connection
  Wire.begin(I2C_ADDRESS);
  Wire.onReceive(receiveEvent);
  Wire.onRequest(requestEvent);
}

void loop()
{
  uint8_t buffer[2];

  // check for keys
  if (keypad.getKeys())
  {
    for (uint8_t i = 0; i < LIST_MAX; i++)
    {
      if (keypad.key[i].stateChanged)
      {

#ifdef SERIALDEBUG
        Serial.print("Millis: ");
        Serial.print(millis());
        Serial.print(" ");
        Serial.print("Key: ");
        Serial.print((int)keypad.key[i].kchar);
        Serial.print(" ");
        Serial.print("State: ");
        Serial.println(keypad.key[i].kstate);
#endif

        // state changed, send key and state
        buffer[0] = keypad.key[i].kchar;
        buffer[1] = keypad.key[i].kstate;
        kSerial.write(buffer, 2);

        // set/delete hold timestamp
        if (autoRepeatInterval > 0)
        {
          switch (keypad.key[i].kstate)
          {
          case KeyState::HOLD:
            setKeyHoldInfo((uint8_t)keypad.key[i].kchar);
            break;

          case KeyState::RELEASED:
            deleteKeyHoldInfo((uint8_t)keypad.key[i].kchar);
            break;

          default:
            break;
          }
        }
      }
    }
  }
  // check for auto repeat
  if (autoRepeatInterval > 0)
  {
    unsigned long currentMillis = millis();
    for (uint8_t i = 0; i < LIST_MAX; i++)
    {

      if (keyHoldInfo[i].keyCode != 0)
      {
        bool genEvent = false;
        if ((keyHoldInfo[i].autoRepeatCount < fastAutoRepeatDelay) || (fastAutoRepeatDelay == 0))
        {
          // check if it is time to generate a key repeat event
          if (currentMillis - keyHoldInfo[i].holdTimestamp > autoRepeatInterval)
          {
            genEvent = true;
          }
        }
        else
        {
          // check if it is time to generate a key fast repeat event
          if (fastAutoRepeatInterval > 0)
          {
            if (currentMillis - keyHoldInfo[i].holdTimestamp > fastAutoRepeatInterval)
            {
              genEvent = true;
            }
          }
        }
        if (genEvent)
        {

#ifdef SERIALDEBUG
        Serial.print("Millis: ");
        Serial.print(millis());
        Serial.print(" ");
        Serial.print("Key: ");
        Serial.print(keyHoldInfo[i].keyCode);
        Serial.print(" ");
        Serial.print("State: ");
        Serial.println(KEYSTATE_AUTOREPEAT);
#endif
          buffer[0] = keyHoldInfo[i].keyCode;
          buffer[1] = KEYSTATE_AUTOREPEAT;
          kSerial.write(buffer, 2);
          keyHoldInfo[i].holdTimestamp = currentMillis;
          if (fastAutoRepeatInterval > 0)
          {
            keyHoldInfo[i].autoRepeatCount++;
          }
        }
      }
    }
  }
}

// event handler for I2C commands
void receiveEvent(int count)
{
  while (Wire.available())
  {
    char c = Wire.read();
    if (c == CMDINDENTIFIER)
    {
      int command = Wire.read();
      switch (command)
      {
      case CMD_RESET:
        onReset();
        break;

      case CMD_GETVERSION:
        onGetVersion();
        break;

      case CMD_SETHOLDTIME:
        onSetHoldTime();
        break;

      case CMD_SETDEBOUNCETIME:
        onSetDebounceTime();
        break;

      case CMD_SETAUTOREPEATINTERVAL:
        onSetAutoRepeatInterval();
        break;

      case CMD_SETFASTAUTOREPEATINTERVAL:
        onSetFastAutoRepeatInterval();
        break;

      case CMD_SETFASTAUTOREPEATDELAY:
        onSetFastAutoRepeatDelay();
        break;

      default:
        break;
      }
    }
  }
}

// request handler
void requestEvent()
{
  switch (pendingRequest)
  {
  case CMD_GETVERSION:
    Wire.write(VERSION_MAJOR);
    Wire.write(VERSION_MINOR);
    Wire.write(VERSION_REVISION);
    pendingRequest = -1;
    break;
  }
}

// reset the keyboard
void onReset()
{
  reset();
}

// prepare to answer version request
void onGetVersion()
{
  pendingRequest = CMD_GETVERSION;
}

// set new hold time value
void onSetHoldTime()
{
  holdTime = Wire.read();
  keypad.setHoldTime(holdTime);
}

// set new debounce time value
void onSetDebounceTime()
{
  debounceTime = Wire.read();
  keypad.setDebounceTime(debounceTime);
}

// sets the key repeat interval
// set to 0 to disable auto repeat
void onSetAutoRepeatInterval()
{
  autoRepeatInterval = Wire.read();
  initKeyHoldInfo();
}

// sets the key fast repeat interval
// set to 0 to disable fast auto repeat
void onSetFastAutoRepeatInterval()
{
  fastAutoRepeatInterval = Wire.read();
}

// sets the delay before changing to fast repeat interval
void onSetFastAutoRepeatDelay()
{
  fastAutoRepeatDelay = Wire.read();
}

// deletes the hold timestamp for this key
void deleteKeyHoldInfo(uint8_t keyCode)
{
  for (int i = 0; i < LIST_MAX; i++)
  {
    if (keyHoldInfo[i].keyCode == keyCode)
    {
      keyHoldInfo[i].keyCode = 0;
      keyHoldInfo[i].holdTimestamp = 0;
      keyHoldInfo[i].autoRepeatCount = 0;
      break;
    }
  }
}

// sets the hold timestamp for this key
void setKeyHoldInfo(uint8_t keyCode)
{
  for (int i = 0; i < LIST_MAX; i++)
  {
    if (keyHoldInfo[i].keyCode == 0)
    {
      keyHoldInfo[i].keyCode = keyCode;
      keyHoldInfo[i].holdTimestamp = millis() + autoRepeatInterval;
      keyHoldInfo[i].autoRepeatCount = 0;
      break;
    }
  }
}

// initializes the key hold timestamp table
void initKeyHoldInfo()
{
  for (int i = 0; i < LIST_MAX; i++)
  {
    keyHoldInfo[i].keyCode = 0;
    keyHoldInfo[i].holdTimestamp = 0;
    keyHoldInfo[i].autoRepeatCount = 0;
  }
}

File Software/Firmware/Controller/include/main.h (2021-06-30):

// main.h

// Nixie Calculator Firmware
// Version 0.1.1 (alpha) - June 30, 2021

// Copyright (C) 2021 highvoltglow
// Licensed under the MIT License

#pragma once

//- INCLUDES
#include <Arduino.h>
#include <Wire.h>
#include <Adafruit_Neopixel.h> // https://github.com/adafruit/Adafruit_NeoPixel
#include <SoftwareSerial.h>    // https://github.com/plerup/espsoftwareserial
#include <OneWire.h>
#include <DallasTemperature.h>
#include <nvs_flash.h>
#include <DisplayHandler.h>
#include <KeyboardHandler.h>
#include <Settings.h>
#include <Calculator.h>
#include <Clock.h>

//- VERSION
#define MAJOR_VERSION 0
#define MINOR_VERSION 1
#define REVISION 1

//- DEFINITIONS

// pins
#define PIN_HVENABLE 4
#define PIN_HVLED 5
#define PIN_SHIFT 17
#define PIN_STORE 16
#define PIN_DATA 18
#define PIN_LEDCTL 14
#define PIN_GPSTX 33
#define PIN_GPSRX 32
#define PIN_PIR 35
#define PIN_KINT 27
#define PIN_TEMPERATURE 25

// shift transition
#define SHIFT_BEGIN HIGH
#define SHIFT_COMMIT LOW

// store transition
#define STORE_BEGIN LOW
#define STORE_COMMIT HIGH

// digits
#define DIGIT_COUNT 14
#define DIGIT_OFF 255

// neons
#define DECIMAL_POINT_COUNT 14

// leds
#define LED_COUNT 6

//- ENUMS
enum class sign : uint8_t
{
  plus,
  minus
};

enum class device_mode : uint8_t
{
  calculator,
  clock,
  menu
};

//- GLOBALS
Adafruit_NeoPixel leds(LED_COUNT, PIN_LEDCTL, NEO_GRB + NEO_KHZ800);
Settings *pSettings;
DisplayHandler displayHandler(DIGIT_COUNT, DECIMAL_POINT_COUNT, display_mode::in16, PIN_DATA, PIN_STORE, PIN_SHIFT);
KeyboardHandler keyboard;
SoftwareSerial keyboardCom(PIN_KINT);
Calculator calculator(DIGIT_COUNT);

uint32_t pirTimestamp = 0;
uint32_t pirInterval = 5 * 60; // 5 minutes
uint32_t gpsSyncTimestamp = 0;
uint32_t gpsSyncInterval = GPS_SYNC_INTERVAL_SHORT; // 15 seconds
uint32_t syncTimestamp = -5000;
bool highVoltageOn = false;

// calculator stuff
bool decimalMode = false;
bool numericMode = false;
sign currentNumberSign = sign::plus;
double currentNumber = 0.0;
String display;
device_mode deviceMode = device_mode::calculator;

// Temperature sensor
OneWire oneWire(PIN_TEMPERATURE);
DallasTemperature tempSensor(&oneWire);
DeviceAddress tempSensorAddress;
bool tempSensorAvailable = false;
volatile unsigned long temperatureCheckTimestamp;
unsigned long temperatureCheckInterval = 5;
unsigned long temperatureConversionDelay = 1;
float currentTemperature;

// declarations
void hvON();
void hvOFF();
bool getTempSensor();
void checkTemperature();
void showVersion();

// callback functions
void onKeyboardEvent(uint8_t keyCode, key_state keyState, bool functionKeyPressed);

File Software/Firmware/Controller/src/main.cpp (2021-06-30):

// main.cpp

// Nixie Calculator Firmware
// Version 0.1.1 (alpha) - June 30, 2021

// Copyright (C) 2021 highvoltglow
// Licensed under the MIT License

//- INCLUDES
#include <main.h>

// setup
void setup()
{
  Serial.begin(115200);

  // set pin modes
  pinMode(PIN_HVENABLE, OUTPUT);
  pinMode(PIN_HVLED, OUTPUT);
  pinMode(PIN_LEDCTL, OUTPUT);
  pinMode(PIN_PIR, INPUT);

  // make sure HV is off
  hvOFF();

  // init I2C
  Wire.begin();

  // init keyboard stuff
  keyboardCom.begin(9600);
  keyboard.begin(keyboardCom);
  keyboard.attach(onKeyboardEvent);

  displayHandler.clearDisplay();

  //nvs_flash_init();
  //pSettings = new Settings();

  // pir interrupt

  // init LEDs
  leds.begin();
  leds.clear();
  leds.show();
  Serial.println();

  // wait for keyboard start
  delay(1000);

  // requests version from keyboard
  keyboard.requestVersion();
  keyboard.setAutoRepeatInterval(500);

  // temperature sensor
  tempSensor.begin();
  tempSensorAvailable = getTempSensor();
  currentTemperature = 0;
  if (tempSensorAvailable)
  {
    tempSensor.setResolution(10);
    tempSensor.setWaitForConversion(false);
    temperatureCheckTimestamp = millis() + (temperatureCheckInterval * 1000);
  }

  // turn on high voltage
  hvON();

  // show version
  showVersion();
  delay(750);

  //
  switch (deviceMode)
  {
  case device_mode::calculator:
    displayHandler.Show(calculator.getDisplay());
    break;

  default:
    break;
  }
}

// main loop
void loop()
{
  keyboard.process();
  if (tempSensorAvailable)
  {
    checkTemperature();
  }
}

void onKeyboardEvent(uint8_t keyCode, key_state keyState, bool functionKeyPressed)
{
  switch (deviceMode)
  {
  case device_mode::calculator:
    // calculator is keyboard driven, send key event and update display
    calculator.onKeyboardEvent(keyCode, keyState, functionKeyPressed);
    displayHandler.Show(calculator.getDisplay());
    break;

  default:
    break;
  }
}

void showVersion()
{
  char buffer[20];
  sprintf(buffer, "%02u.%02u.%02u  %02u.%02u.%02u", MAJOR_VERSION, MINOR_VERSION, REVISION,
          keyboard.getMajorVersion(), keyboard.getMinorVersion(), keyboard.getRevision());
  displayHandler.Show(buffer);
}

void hvON()
{
  if (!highVoltageOn)
  {
    highVoltageOn = true;
    digitalWrite(PIN_HVENABLE, HIGH);
    digitalWrite(PIN_HVLED, HIGH);
  }
}

void hvOFF()
{
  if (highVoltageOn)
  {
    highVoltageOn = false;
    digitalWrite(PIN_HVENABLE, LOW);
    digitalWrite(PIN_HVLED, LOW);
  }
}

bool getTempSensor()
{
  bool result = false;
  Serial.println(tempSensor.getDeviceCount());
  for (int i = 0; i < tempSensor.getDeviceCount(); i++)
  {
    tempSensor.getAddress(tempSensorAddress, i);
    result = true;
  }
  return result;
}

void checkTemperature()
{
  static bool requestPending = false;
  unsigned long currentMillis = millis();
  if (!requestPending)
  {
    if (currentMillis - temperatureCheckTimestamp > (temperatureCheckInterval * 1000))
    {
      tempSensor.requestTemperatures();
      temperatureCheckTimestamp = currentMillis;
      requestPending = true;
    }
  }
  else
  {
    if (currentMillis - temperatureCheckTimestamp > (temperatureConversionDelay * 1000))
    {
      currentTemperature = tempSensor.getTempC(tempSensorAddress);
      requestPending = false;
      Serial.println(currentTemperature);
    }
  }
}
